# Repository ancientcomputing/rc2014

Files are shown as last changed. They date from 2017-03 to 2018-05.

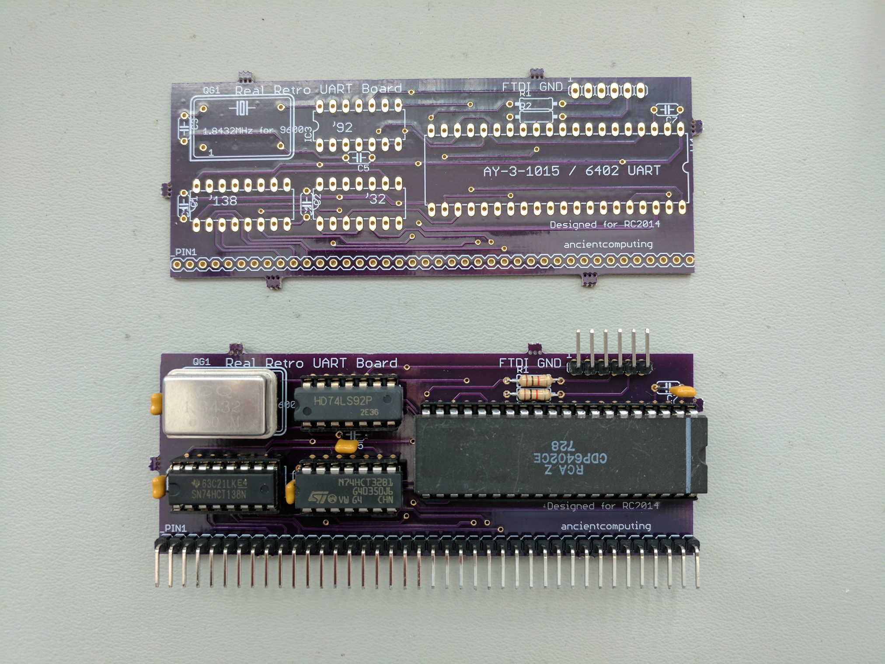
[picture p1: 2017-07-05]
eagle/realretro_uart_board/rruart-small.jpg

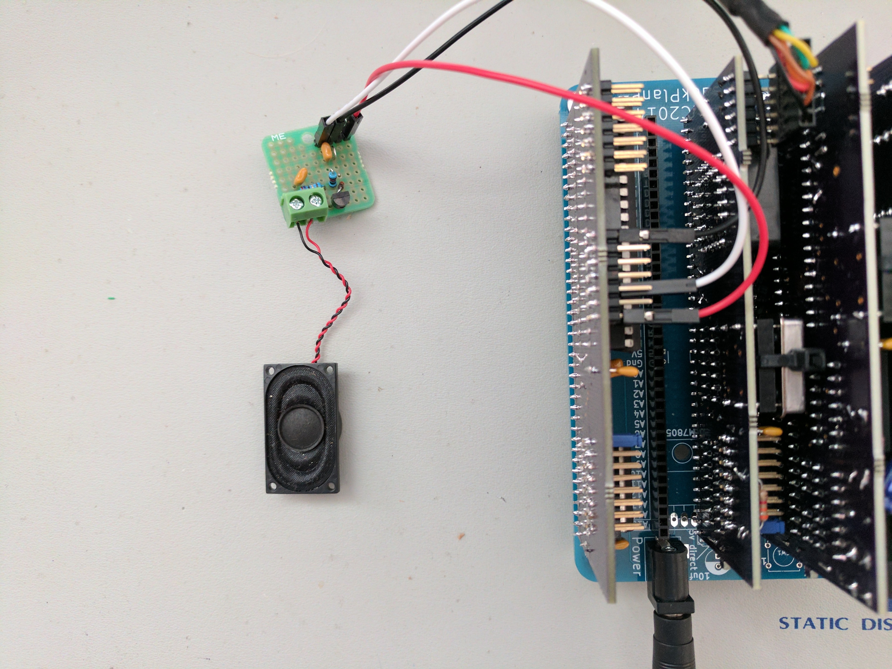
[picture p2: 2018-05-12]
source/6502/6522/speaker_board.jpg

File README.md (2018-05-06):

# RC2014
I consider Spencer Owen's RC2014 (http://rc2014.co.uk) the new S100 of the ancient computing era.
<p>
Spencer started off by designing a CPU and a family of modules around the ancient Zilog Z80 CPU. This is actually very similar to the original S100 bus design that was a derivative of the 8080 bus.
<p>
Since I'm a modder at heart, I've gone ahead and modified some of the Z80 software that originally came with the RC2014.
<p>
I have also developed a number of RC2014-compatible plug-in boards. These include a variety of memory and serial (UART) boards and more importantly, boards that allow the use of other CPUs like the <a href="https://en.wikipedia.org/wiki/Intel_8085">Intel 8085</a> and <a href="https://en.wikipedia.org/wiki/MOS_Technology_6502">6502</a> with the RC2014.
<p>
This repo holds my mods/additions and general contributions to the RC2014 community.
<p>
<hr>
<p>
<b>Software</b>
<p>
The source folder contains source code of projects related to the RC2014.
<p>
The 6502 sub-folder contains all the 6502-related source code including the Monitor/Debugger and Enhanced BASIC.
<p>
The Z80_8080 sub-folder contains all source code for Z80 and 8080 software including the Monitor/Debugger, MS BASIC, IMSAI 8K BASIC (for 8080) and various BIOS.
<p>
The original code that shipped with the RC2014 is at <a href="searle.hostei.com/grant">searle.hostei.com/grant</a>
<p>
The primary RC2014 Github repo is at: https://github.com/RC2014Z80/RC2014
<p>
<hr>
<p>
<b>ROM</b>
<p>
ROM images you can burn into EPROM/EEPROM for use with the RC2014 can be found in the ROM folder.
<p>
Not all combinations of CPU, serial, Monitor/Debugger, BASIC and ROM image sizes are available. When in doubt you can ask questions on the <a href="https://groups.google.com/forum/#!forum/rc2014-z80">RC2014 group</a> or <a href="http://forum.6502.org/">http://forum.6502.org/</a>.
<p>
<hr>
<p>
<b>RC2014 Add-on Modules</b>
<p>
The <b>eagle</b> folder contain a number of designs for add-on boards for the RC2014. The designs are in the form of Eagle files which can be used to order PCBs from manufacturers that can take .brd files. Or you can download the free version of Eagle and generate the necessary gerber files for your PCB vendor of choice.
<p>
Do also watch out for the OSH Park logos. Those are links to projects that I have shared on OSH Park, and you can order the boards directly from them. And no, I don't make a commission etc from your OSH Park orders.
<p>
For a full list of my shared projects, check out this <a href="https://oshpark.com/profiles/ancientcomputing">link</a>.
<p>
I have put some popular boards up for sale on <a href="https://www.tindie.com/stores/ancientcomputing/">Tindie</a>.
<p>
<hr>
<p>
Lastly, check out the documentation in the docs folder.
<p>
<hr>
<p>
Blog: http://ancientcomputing.blogspot.com

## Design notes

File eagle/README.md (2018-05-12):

<b>Eagle files for RC2014 add-on boards</b>
<p>
<b>16550 board (TESTED)</b>: Simple board for 16550, 16C550 and similar UART devices. Can be used with 1.8432MHz or 7.3728MHz oscillators. Note that pin 1 (GND) of the FTDI connector is on the left (looking at the board with the bus connector at the bottom).
<p>
The port address starts at 80H. A new BIOS is available. See source/16x550. Binaries are at rom/16x550.
<p>
There is no option to power the system from the FTDI header.
<p>
<b>16550 board Rev B (TESTED)</b>: A variant of the 16550 board implementation. Using 74HCT03 open collector gates, particularly to drive the /INT line. This means that other peripherals can also drive the /INT line. 
<p>
The port address starts at C0H. A new BIOS will be made available for this. For the impatient, just change the uart_base value to 0c0h from 80h.
<p>
<b>16550 board Rev C (TESTED)</b>: Yet another variant of the 16550 board implementation. This time, it uses the PLCC version of the 16550 which is still a current part. This board is also compatible with the new 16C750 which has 64-character FIFOs!
<p>
<b>z80_board (TESTED)</b>: This is an opinionated implementation of a CPU module for the RC2014. It is designed for the v1.0 bus but may work for the Pro/v2 bus. The opinionated parts of the design is a bona fide reset circuit (the firmware should start up on power up), and the use of a crystal oscillator.
<p>
The crystal oscillator can be connected to the RC2014 bus or not. The decoupling of the Z80's clock from the bus clock means that you are no longer bounded by the requirements of the UART baudrate. You will be able to run the Z80 at 20MHz (assuming you have the 20MHz part and that the bus doesn't impact the high frequency signals too much).
<p>
This Z80 board is compatible with other RC2014 modules. If you plan to use this with the 68B50 ACIA module, you will have to use a 7.3728MHz oscillator and short the CLOCK jumper.
<p>
<b>8085_board (TESTED)</b>: Use another CPU with the RC2014! The 8085 is the step-sibling of the Z80. This implementation exposes the SID/SOD lines to an FTDI header so that you can run with a serial terminal without the use of a UART card. A 6.144MHz crystal is recommended for compatibility with the Tiny Basic found <a href="https://github.com/ancientcomputing/8080_8085/tree/master/Tiny_Basic">here</a>.
<p>
A Monitor can also be found in the <a href="https://github.com/ancientcomputing/rc2014/tree/master/rom/8080_8085/monitor/">8085 folder</a>.
<p>
<b>Real Retro 3KB RAM board aka rr3kram (TESTED)</b>: Remember when 3KB was a lot of memory? The Real Retro 3KB RAM board tries to relive that experience. It uses 3 pairs of 2114 RAM chips to deliver a massive 3KB of memory.
<p>
With 200ns devices, it will even work with the Z80 CPU+ board equiped with a blistering fast 14MHz Z80.
<p>
The original board design had disconnected A0, A1 lines which have now been fixed.   
<p>
<b>Real Retro UART board (TESTED)</b>
<p>
A basic UART board using ancient UART devices like the 6402, AY-3-1015 or similar.
<p>
<b>Simple ROM/RAM board (TESTED)</b>
<p>
A simple board providing 32KB of RAM and 32KB of ROM. Usable with EPROM or EEPROM. Switchable to allow ROM at the top of memory or at the bottom of memory. This provides for compatibility with 6502 or 680x CPU boards.
<p>
<b>6502 CPU Board (TESTED)</b>
<p>
Run the 6502 microprocessor on the RC2014!
<p>
The 6502, along with the Z80, powered much of the home computer industry in the late 1970s and 1980s.
<p>
My blog <a href="https://ancientcomputing.blogspot.com">ancientcomputing.blogspot.com</a> has a number of articles that cover how the 6502 bus was made to work on the RC2014 bus and which RC2014 boards can work (with or without minor modifications) with the 6502 CPU board.
<p>
<b>6502 CPU Board RevB (TESTED)</b>
<p>
The RevB version of the 6502 CPU board gives you the option of inverting the A14 address line as well. You can use it with the RC2014 64KB RAM card to build a system with 48KB of usable RAM.
<p>
<b>6522 VIA Board (TESTED)</b>
<p>
You can start building up a 6502-based RC2014 system using native 6502 peripherals starting with the 6522 VIA board.
<p>
<hr>
<p>
<b>IMPORTANT</b>: These designs unless described otherwise are at the prototype stage as of now. I have put in the initial board orders at OSH Park and have not tested any of the designs. If you do find errors, please flag them!
<p>
kicadis are encouraged to convert the files to kicad format with the sole requirement that the converted files are made freely available aka "open source"...
<p>
Copyright Ben Chong and freely licensed back to the community.
<p>
<hr>
<p>

<p>

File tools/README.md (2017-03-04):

I found that some device programmers expect a single source file to burn an EPROM.
So romit.sh is used to combine both init32K and bas32K binaries into a single binary file.
This is a basic shell script file that works on Mac OS X and should work in a Linux environment as well.

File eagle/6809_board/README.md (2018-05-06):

<b>6809 CPU Board for the RC2014</b>
<p>
These are the EAGLE files for the RC2014 6809 CPU Board.
<p>
The A15 line selects the inverted A15 signal from the 6809. This allows you to use the standard RC2014 memory and I/O boards by inverting the 2 halves of the memory space: ROM sits at top of memory and RAM at the bottom of memory.
<p>
The I/O space is decoded by the 74HCT688 and is mapped as a 256-byte block to the start of 0C000H. You will map the Z80 I/O addresses to the 6809 I/O space by adding 0C000H.
<p>
Compatibility:
<br>TBD
<p>
You can have boards made at OSH Park at the following link:
<p>

<p>

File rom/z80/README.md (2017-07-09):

<b>ROMs for the RC2014</b>
<p>
The ROM images are organized according to which serial board (UART) they are used with.
<p>
68B50: Original RC2014 serial I/O board
<p>
sio: Dr Baker's SIO board
<p>
16x550: My original 16x550 UART board with 80h base address
<p>
16x550_revb: RevB version of my 16x550 UART board with c0h base address. This version can also be used with the RevC UART board.
<p>
ROM images for the 8085 CPU board have been moved to rom/8080_8085

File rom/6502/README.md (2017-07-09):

<b>ROM images for RC2014 6502 CPU Board</b>
<p>
monitor_ehbasic : Monitor/Debugger and Enhanced BASIC - These images are more up-to-date
<p>
monitor : Monitor/Debugger only - These images lag the source code

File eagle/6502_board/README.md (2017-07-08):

<b>6502 CPU Board for the RC2014</b>
<p>
These are the EAGLE files for the RC2014 6502 CPU Board.
<p>
Connect JP1 if you aren't using the Western Design Center 65C02 chip. This is the VPB output on the WDC chip, but on other 65(C)02 chips this has to be connected to GND.
<p>The A15 line selects the inverted A15 signal from the 6502. This allows you to use the standard RC2014 memory and I/O boards by inverting the 2 halves of the memory space: ROM sits at top of memory and RAM at the bottom of memory.
<p>
The I/O space is decoded by the 74HCT688 and is mapped as a 256-byte block to the start of 0C000H. You will map the Z80 I/O addresses to the 6502 I/O space by adding 0C000H.
<p>
Compatibility:
<br>TBD
<p>
You can have boards made at OSH Park at the following link:
<p>

<p>
Otherwise, you can order the RevB boards on <a href="https://www.tindie.com/products/9916/">Tindie</a>.

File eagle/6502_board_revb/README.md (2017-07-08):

<b>6502 CPU Board for the RC2014 RevB</b>
<p>
This is the RevB version of the board.
<p>
New:
<br>
- Optional jumper to connect R/W to pin 39 of the bus
<br>
- A14 can be inverted. Inverting A14 will allow you to use the RC2014 64KB RAM board. Configure that board for 48KB of RAM, starting from 4000h. The inverted A14 will map the 48KB to 0-BFFFh in the 6502 address space, giving you a whopping 48KB of RAM!
<br>
- NMI can be accessed with a test pin/point
<br>
- You can use a 1/2 size oscillator.
<p>
Otherwise this board works the same as the original version.
<p>
You can have boards made at OSH Park at the following link:
<br>

<p>
Otherwise, you can order boards on <a href="https://www.tindie.com/products/9916/">Tindie</a>.

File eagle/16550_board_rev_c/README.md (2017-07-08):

<b>16550 UART Board for RC2014</b>
<p>
This is RevC of the 16550 UART Board, designed for RC2014 systems.
<p>
Unlike earlier versions, this board takes the PLCC version of the 16550. I have successfully tested it with a TL16C550CFN from Mouser (part: 595-TL16C550CFN).
<p>
Also, as you can see from the Mouser part number, PLCC versions of the 16C550 are still commercially available. The DIP/DIL-40 versions are no longer so.
<p>
The use of a 16C550 in a 6502 system is important (vs the 16550 version) because the 6502 BIOS enables autoflow control. This provides a means of throttling the byte stream from your PC when you are uploading an Intel Hex file.
<p>
The other major change is the use of a 74HCT138 to give you more addressing options. This allows you to use more than one board in a system: you just need to make sure that each board uses a different port address. Of course, the software needs to be appropriately modified to access port addresses other than C0H which is the default one.
<p>
Finally, the PLCC socket is a standard part and can be ordered from Mouser (part: 806-PX-44LCC) or Jameco.
<p>
You can have boards made at OSH Park:<br>

<p> 
Or order them on <a href="https://www.tindie.com/products/9981/">Tindie</a>.

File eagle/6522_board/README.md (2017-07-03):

<b>6522 VIA Board for the RC2014</b>
<p>
These are the Eagle files for the 6522 VIA Board for the RC2014.
<p>
The board is designed to work with the 6502 CPU Board.
<p>
If you have the initial revision (revA) of the 6502 CPU board, be sure to link a wire from the R/W signal of the 6502 to pin 39 of the RC2014 bus connector. The 6522 takes the R/W signal from that pin. RevB of the 6502 CPU board does not need that change but you want to make sure that the R/W jumper is closed.
<p>
Be sure to use a 6522 that is speed matched to the 6502 CPU.
<p>
Check out some test code <a href="https://github.com/ancientcomputing/rc2014/tree/master/source/6502/6522">here</a>.

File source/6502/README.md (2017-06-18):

<b>Source code for 6502 CPU</b>
<p>
This sub-repository contains source code for programs/tools for the RC2014 6502 CPU board.
<p>
<b>monitor</b>: Simple Monitor/Debugger for the 6502
<p>
<b>ehbasic</b>: Lee Davison's Enhanced BASIC for the 6502
<p>

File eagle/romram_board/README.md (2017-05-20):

<b>Simple ROM/RAM Board for RC2014</b>
<p>
This is a simple ROM+RAM board that fully outfit an RC2014 system with memory.
<p>
Instead of ROM and RAM on separate boards, I wanted to combine them in order to reduce the number of boards needed to put together a basic system. 
<p>
The design is also very basic. Rather than trying to boil the ocean, I elected to assume the basic 32KB-32KB ROM-RAM split that is very common today among SBC designs.
<p>
The only "fancy" features are:
<br>1. Ability to select between 27256 EPROM and 28C256 EEPROM devices.
<br>2. The ability to put RAM at the top of memory à la Z80/8080 or RAM at the bottom of memory à la 6502/680x. Conversely, ROM will be at the bottom or top of memory respectively.
<p>
Fellow modders can make use of the board as a switchable ROM/RAM board by swapping in a "PAGE" signal to the A15 input of the 74HCT139.
<p>
Boards can be ordered from OSH Park at the following link:
<p>

<p>
Parts are:
<br>27256 or 28C256
<br>Most 32KB RAM devices include those that are shipped with the RC2014 RAM cards<br>74LS139, 74HCT139 or 74ACT139
<p>

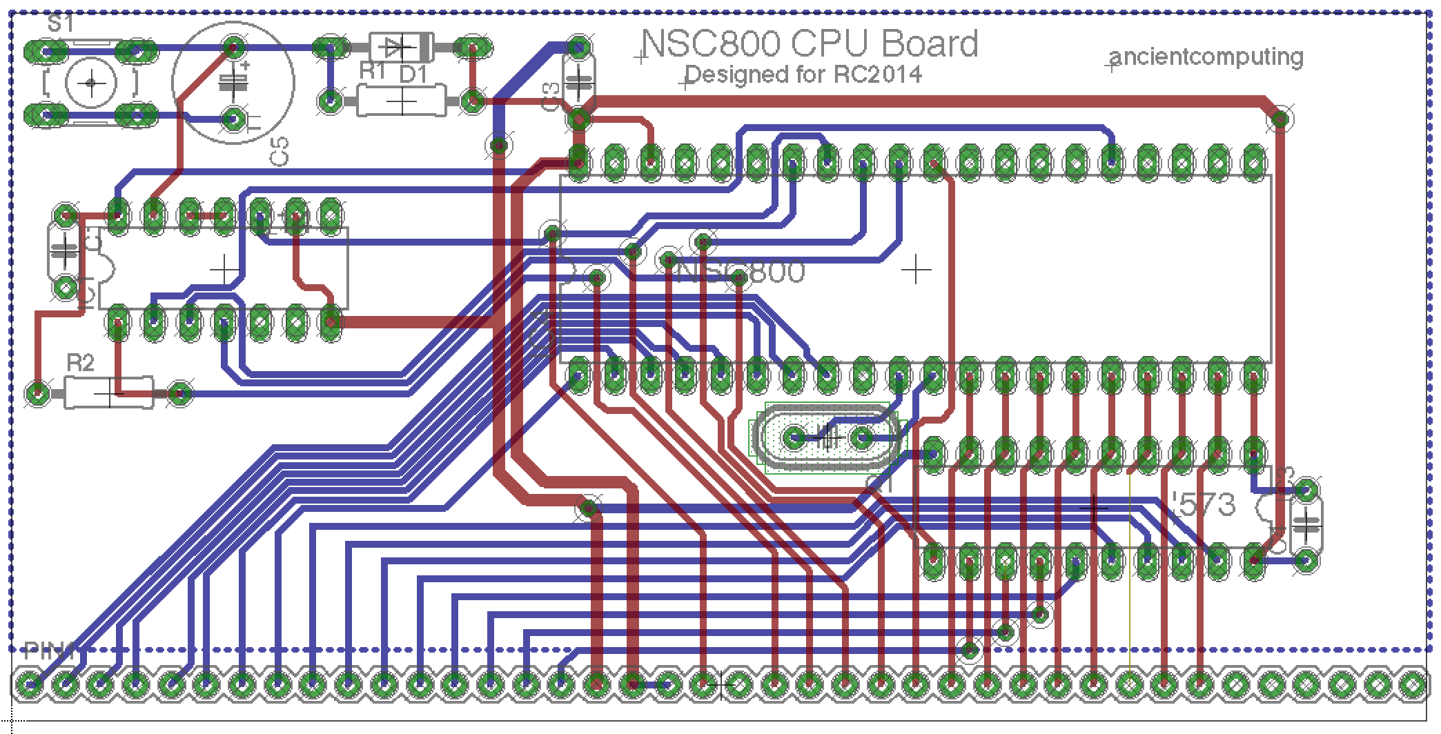
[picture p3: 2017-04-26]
eagle/NSC800_board/rc2014_nsc800.png

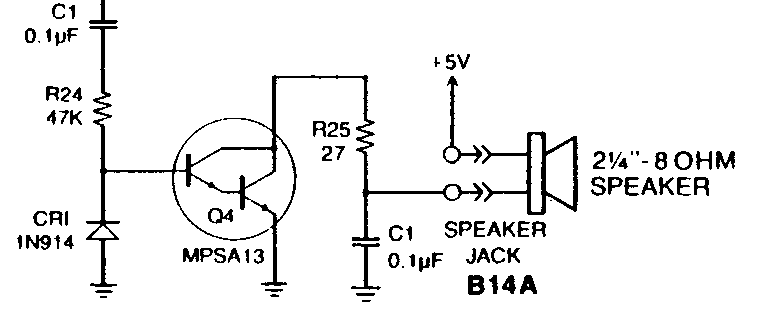
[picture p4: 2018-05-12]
source/6502/6522/a2_speaker_driver.png

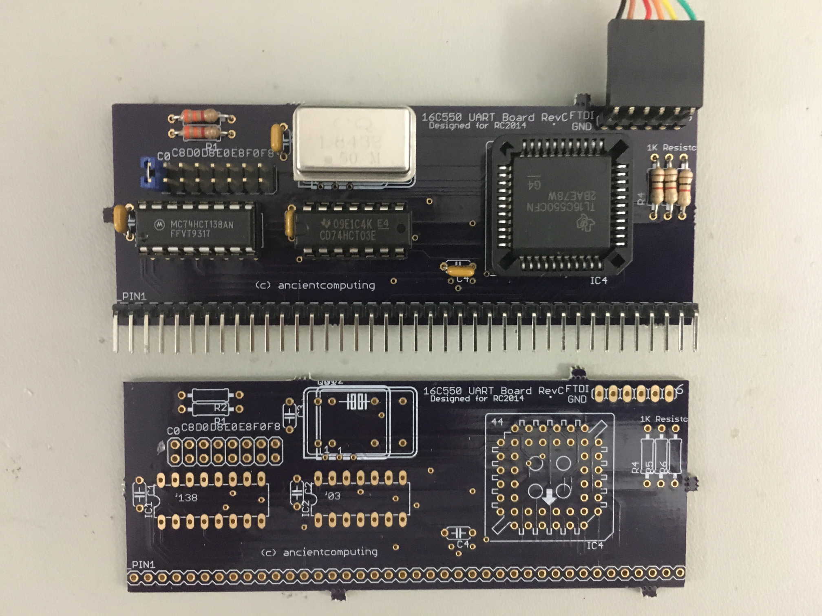
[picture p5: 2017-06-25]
eagle/16550_board_rev_c/16550_board_rev_c.jpg

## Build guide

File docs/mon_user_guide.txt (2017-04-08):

Monitor/Debugger for the RC2014
User Guide

Acknowledgements

The Monitor/Debugger for the RC2014 is based heavily on work done by others. 
Acknowledgements are in the source code.

Introduction

The Monitor/Debugger for the RC2014 is a "machine language" monitor that is very similar
in functionality to those shipped with the original microcomputers of the late 1970s to
early 1980s. This with the exception that user interaction is with a serial terminal as
opposed to a bunch of switches and LED hexadecimal displays as with the earliest 
microcomputers.

A Monitor/Debugger allows users to type in programs that they have assembled into machine
code: the actual instructions that microprocessors recognize. It also allows users to
examine and modify memory, execute programs, and set breakpoints and view registers when 
breakpoints are hit.

Many early microcomputers only came with a Monitor/Debugger. Advanced languages like BASIC
were only available as an upgrade. Later home computers dispensed with the Monitor/
Debugger and only shipped with a version of BASIC or even FORTH!

The Monitor/Debugger for the RC2014 was written for folks developing Z80 assembly code
and wanting to load, run and debug their programs on the RC2014.

Installation

The Monitor/Debugger binary is less than 4KB in size. It can be burned into a 27C512 
EPROM that is similar to the one that comes with the RC2014. You can also burn it into a
28C256 if you know how to configure the RC2014 e.g. connecting Jumper 4 on the RC2014 
Mini to Vcc.

The Monitor/Debugger binary filename is "mon.rom" and is found here:
https://github.com/ancientcomputing/rc2014/tree/master/rom

Boot

Boot the RC2014 normally e.g. connect the serial line to a computer running a terminal
emulator or an actual serial terminal, connect the power if applicable, then press and 
release the reset button.

You will see the following:
  RC2014
  Monitor >

The second line is the monitor's command line prompt.

If you press the reset button again, you will see
  RC2014
  C/W?

Press C for cold boot or W for warm boot.

Press W if you want to look at saved breakpoint registers. 

Monitor Commands

When presented with the monitor's command line prompt, you can press a key (on the 
terminal or terminal emulator) to enter a command.

Valid monitor commands are:
?              Print this help
A XXXX         Disassemble from XXXX
C              Continue from Breakpoint
D XXXX         Dump memory from XXXX
E XXXX         Edit memory from XXXX
G XXXX         Go execute from XXXX
H XXXX         Set HEX file start address to XXXX
I XX           Input from port XX
O XX YY        Output YY to port XX
R              Display registers from Breakpoint
:sHLtD...C     Load Intel HEX file, ':' is part of file

Pressing '?' will print the list of valid commands.

Running a program on the RC2014

Let's look at how you can load and execute programs on the RC2014 using the 
Monitor/Debugger.

Most Z80 assemblers or cross-assemblers will generate an Intel HEX file. This file
contains the executable Z80 machine code, but in a human readable format. Although you
will be hardpressed to understand any of it!

To run your new program on the RC2014, you will need to load the code into the RC2014 RAM.

Let's assume that you've written the following little program:

        .ORG 0C000H
        LD      HL, 0
START:
        LD      A, 0AH
        RST     08H
        LD      A, 0Dh
        RST     08H
        LD      A, 'A'
LOOP1:
        RST     08H
        INC     A
        CP      A, 'Z'+1
        JR      NZ, LOOP1
        JP      START

This little program will print the characters A to Z horizontally, then start all over 
again on a new line.

To make this program understandable by a Z80 processor, you will need to assemble it to
generate machine code.

I use the zasm cross-assembler for this. You may use other assemblers.

With zasm, you would type in the following command:
        zasm -u -x test.asm
        
Where test.asm is the text file that contains this little program.

zasm will produce a file called test.hex. If you open this file with a text editor, you 
will see the following contents:

        :170000002100003E0ACF3E0DCF015A5A3E41CF3CFE5B20FAC303C05F
        :00000001FF
        
The leading ':' symbols at the beginning of each line indicates that this is an Intel
HEX file.

The Monitor/Debugger is able to automatically understand that a ':' command means that 
the next set of data that comes over the serial console is the rest of the Intel HEX 
file.

You can either copy the file from the test editor and then paste it onto the terminal
emulator or use, if available, the built-in functions of your terminal emulator to send 
the Intel HEX file over.

For example, I use the Serial terminal emulator on a Mac. This program has a "Send Text
File" feature (Command-T). When I hit Command-T, it will ask me to choose a file to send
over to the RC2014 over the serial port.

HEX File Start Address

Before we send over the Intel HEx file, we need to understand the assembler that 
we're using and how it generates an Intel HEX file.

This is because, when you write a Z80 program, you need to specify where in the memory
space the program will reside and run. Unlike recent microprocessors, Z80 code is not
location independent without a lot of work. Immediate jump instructions, for example, 
may use absolute addresses.

In our little test program, we used the ".ORG 0C000H" command. This means that we have
assembled the code to run from memory location 0C00H (in hexadecimal values).

Unfortunately, zasm doesn't include this information in the Intel HEX file. So if you 
were to load test.hex, it will end up being written to location 0000H. This of course 
does not do anything since the Monitor/Debugger ROM resides in ROM in that location.

So before loading the test.hex file, you need to run the following command:
        h c000

Just press 'h' followed by 'c000' and ENTER.

What this does is to set the load address of the Intel HEX file data at memory location
0C000h which is where the test program need to be located in order to execute correctly.

Sending an Intel HEX file to the RC2014

Once you have set up the 'H' parameter, it is time to send the Intel HEX file to the 
RC2014.

Again, you can copy contents of the file, then paste it onto the terminal emulator
console at the Monitor > prompt.

You will get the following:

Monitor >:.
HEX TRANSFER COMPLETE ERRORS=00 0017 BYTES TRANSFERRED

The '.' is a tick mark and indicates that there was one line of actual data. The result
also indicates that there was no error and that 17H bytes (number again in hexadecimal)
was transferred.

NOTE: Some cross-assemblers set up the load address correctly. However, they do not
include the correct end-record line in the HEX file. If you see the HEX file load stop
and not do anything, press ESC to quit the load process. You will then see the "HEX
TRANSFER COMPLETE ERRORS=..." message.

Execute Your Program!

Now that you have successfully transferred the program to the RC2014, let's run it!

To run the program, type the following at the Monitor prompt:
        g c000<ENTER>

What do you see?

Since we did not include any checks in the program, the only way to halt it is to reset
the RC2014.

Once you hit reset, you will be prompted with:
        C/W?

Hit 'W' for warm start.

Exploring Memory Contents

Now, you may want to double check the contents of the test program at memory location
C000H.

To do this, hit 'D' at the command prompt, followed by the memory address and ENTER:
        d c000<ENTER>

This will give you the following output:

        C000  21 00 00 3E 0A CF 3E 0D CF 01 5A 5A 3E 41 CF 3C ; !..>..>...ZZ>A.<
        C010  FE 5B 20 FA C3 03 C0 00 00 00 10 00 00 00 01 00 ; .[ .............
        C020  FF FF 7F F6 EF 9F DF EF FE FE FF FE FF 7E FF F7 ; .............~..
        C030  00 00 00 20 10 80 00 00 00 00 00 00 00 00 00 00 ; ... ............
        C040  8A CB 45 F5 93 FE 8C DD 02 31 E4 32 EF DB F3 68 ; ..E......1.2...h
        C050  00 40 00 40 04 20 08 00 00 00 00 00 20 00 00 20 ; .@.@. ...... .. 
        C060  A2 C6 B2 DB F9 C0 7E 3C EE C0 2C 72 73 4A F8 AA ; ......~<..,rsJ..
        C070  80 44 00 00 20 80 10 00 48 00 22 04 48 00 28 40 ; .D.. ...H.".H.(@
        C080  BC FC 3F FF FB FD FF DF FF FF FF BF F7 FF FF FE ; ..?.............
        C090  00 00 00 80 00 00 00 00 00 00 00 00 00 00 00 00 ; ................
        C0A0  80 BE 97 E4 DD 52 84 6D 0F DB BD 11 FE 53 C8 E0 ; .....R.m.....S..
        C0B0  00 00 10 00 00 10 00 00 00 80 00 00 00 01 00 20 ; ............... 
        C0C0  A0 23 E7 1B 73 99 7E FD 9E DB D1 F3 B7 B5 96 2A ; .#..s.~........*
        C0D0  08 00 40 00 00 18 50 04 0A 00 20 00 00 10 C0 02 ; ..@...P... .....
        C0E0  38 E3 EB ED AB 87 F3 F3 31 7B BF DB 58 C3 3A 20 ; 8.......1{..X.: 
        C0F0  00 01 00 00 00 00 08 00 00 00 00 04 00 08 20 00 ; .............. .
        Press any key to continue, ESC to abort

As you can see the first byte of the "LD HL,0" instruction is at location C000H.

At this point, you can press any key to see memory at C100H onwards.

Alternatively, you can press ESC to go back to the Monitor prompt.

Examining and Changing Memory

What if you want to change your program without reassembling it and reloading the
Intel HEX file?

For example, in the test program, I want to start the print out with '0' instead of 'A'.

The instruction that loads the A register with 'A' is located at memory location C00CH.
This can be seen from the test.lst file that is generated when you run zasm.

At the Monitor prompt, hit E followed by c000 and ENTER:
        e c000<ENTER> 

You will see:
        C00C : 3E

Where 3E is the LD A instruction. Press 3E to enter the same value. You will see:
        C00C : 3E 3e 3E

Where the second 3e is what you typed and the third 3E is a confirmation that the value
was written to memory and successfully read back.

You will then see the content on the next memory location:
        C00D : 41

Now, 41 is the hexadecimal value for 'A'. To insert '0' instead, type 30 which is the
hexadecimal value for '0'. Thus:
        C00D : 41 30 30

Now run the program again with g c000. What do you see?

Tip: If you want to skip over an address to keep its value, you can hit RETURN

Inline Disassembler

To double check that you made the right change, the Monitor/Debugger includes an inline
disassembler.

At the Monitor prompt, press 'A' followed by c00c and ENTER. Thus:
        a c00c<ENTER>

You will see the following:

        Disassemble from C00C
        Press any key to step, ESC to abort
        C00C 3E 30       LD   A,30H

As you can see, 30H is the new value being loaded into the A register.

If you were to press any key (other than ESC), the disassembler will disassemble the next
instruction. Hence:
        C00E CF          RST  8 

This is the system call to print a character on the screen. Continue press any key to
look at the other instructions of the test program.

Then press ESC to return to the Monitor prompt.

Breakpoints

Breakpoints are places in your program where you pause the program execution. Generally
you want to use a breakpoint to understand the state of the Z80 registers and memory 
contents at a given point in your program. This is very useful for debugging and for 
learning the effect of using certain Z80 instructions that you are unfamiliar with.

To set a breakpoint, all you need to do is to insert the 'RST 30H' instruction where you
want your program to pause.

Let's insert a breakpoint just before the conditional jump instruction. The test program
will now look like:

        .ORG 0C000H
        LD      HL, 0
START:
        LD      A, 0AH
        RST     08H
        LD      A, 0Dh
        RST     08H
        LD      A, 'A'
LOOP1:
        RST     08H
        INC     A
        CP      A, 'Z'+1
        RST     30H
        JR      NZ, LOOP1
        JP      START

Now assemble the program and load the resulting Intel HEX file to the RC2014. Then use 
G command to run the program.

You will see the following:
        A
        Breakpoint at PC=C012
        AF =429B  BC =5A5A  DE =C000  HL =0000  
        AF'=4D09  BC'=FFFF  DE'=FF03  HL'=4D09  
        IX =0018  IY =0000  IR =007F  SP =81FF  
        Press C to continue or ESC to return to Monitor

The first line you see is the output of your program, when it prints the letter 'A'.

Then you see the breakpoint message, telling you that the breakpoint occurred when the 
Z80 was executing the instruction at 0C012H. This is the location where the breakpoint
instruction (RST 30H) is located.

The next 3 lines show the contents of the various Z80 registers. You can see here that
the A register now contains 42H (the B character) because we incremented it with the 
'INC A' instruction.

At this point, you can either press C to continue the program or ESC to return to the
Monitor/Debugger.

Let's try pressing C first.

Now you will see the following:
        B
        Breakpoint at PC=C012
        AF =439B  BC =5A5A  DE =C000  HL =0000  
        AF'=4D09  BC'=FFFF  DE'=FF03  HL'=4D09  
        IX =0018  IY =0000  IR =0040  SP =81FF  
        Press C to continue or ESC to return to Monitor

The first line is the program printing out the 42H value from the A register. This is
again followed by the breakpoint message, then the contents of the registers.

Now press ESC to return to the Monitor/Debugger. You will now see the Monitor prompt.

From the Monitor prompt, you can use the various commands we have already reviewed e.g. 
to look at or modify memory contents etc.

However, from the Monitor prompt, you can also press C. This command will continue the
test program from the last breakpoint!

Try it!

You will see:
        C
        Breakpoint at PC=C012
        AF =449B  BC =5A5A  DE =C000  HL =0000  
        AF'=4D09  BC'=FFFF  DE'=FF03  HL'=4D09  
        IX =0018  IY =0000  IR =0001  SP =81FF  
        Press C to continue or ESC to return to Monitor

Where the first line is the next character in the A register that is now being printed 
out.

Press ESC to return to the Monitor prompt.

From the Monitor prompt, you can press R to look at the contents of the registers.

Changing Register Contents

The Monitor/Debugger does not have a command to allow you to change breakpoint registers
directly. 

You will just need to modify the memory locations where the registers are 
stored when a breakpoint occurs. When the C command is executed, the Z80 registers are 
loaded from those memory locations.

The locations are the following:

Register        Address
A               8034H
BC              8036H
DE              8038H
HL              803AH
A'              803CH
BC'             803EH
DE'             8040H
HL'             8042H
IX              8044H
IY              8046H
SP              804AH
PC              804CH

You can use the E command to change the registers individually, then use the C command
to continue your program with the new register values.

IMPORTANT NOTE:
The breakpoint handler code in the Monitor/Debugger will switch to the Monitor stack. If
your application works with data on the stack or use subroutines, you will want to use
your own stack space.

To do this, include the following line at the start of your program:
        LD      SP, 0FFFFH

This instruction will load the Z80 Stack Pointer with 0FFFFH which will place the top
of your stack space at the top of RAM memory.

I/O Ports

The I command allows you to read from an input port.

At the Monitor prompt, press I followed by the port address:
        I 80

You will see:
        i 80 02

The value 02H is what is read from the port 80H which is the 68B50 serial port controller
of the RC2014.

The O command allows you to write a byte to an output port.

At the Monitor prompt, press O followed by the port address and data you want to output:
        I 82 41

You will see:
        o 82 41A

Now where did that 'A' come from?

Well, you just wrote 'A' to the transmit port of the 68B50 serial port controller, which
sent it to your terminal emulator program, which then displayed it!

Try writing to port 82H values like 0DH (carriage return) or 0AH (linefeed)!

!NEW! Monitor/Debugger with BASIC

A new ROM image, monbas.rom, is available at the following URL:
https://github.com/ancientcomputing/rc2014/tree/master/rom

The monbas.rom image is a 16KB image that contains both the Monitor/Debugger and a 
slightly tweaked BASIC.

To use this, you will want to use Spencer's newest Pageable ROM Module board. Set it up
for 16KB starting at address 0000H.

By default, you will always boot to the Monitor/Debugger.

To invoke BASIC, use the "G" command for address 1000H:
        g 1000

To warm start BASIC, use the 1003H address instead:
        g 1003

To switch back to the Monitor, use the "monitor" keyword in BASIC. It will basically
restart the system.

Tips and Tricks

Returning to the Monitor

To return to the Monitor/Debugger from your program, you can jump to the Monitor
warm start entry point. 

To do this insert the following line to the end of your program:
        JP      153H

153H is the memory address (in hexadecimal) of the Monitor warm start routine.

If you want to capture the contents of the CPU registers at the end of your program,
just add a breakpoint to the end i.e. thr RST 30H instruction.

Update: The new 0.7.0 version of the Monitor/Debugger/BASIC pushes the entry point of
the Monitor before calling your program. So you can use a simply RET to return to the
Monitor. Assuming that you did not change the stack, of course!

Resetting the RC2014

To reset the RC2014 from your program, just jump to memory location 0. Thus:
        JP      0H

Memory Map

The Monitor/Debugger uses RAM from 8000H to 81FFH.

Details of how this memory is used can be found in the source code.

Serial Terminal Emulator

I use a Mac for development along with an FTDI-based USB-to-serial cable. For the 
terminal emulator, I use a program called Serial. 

Serial gives you options to send files (either RAW or text) over to the RC2014.

In order to slow down the transfers so that the RC2014 does not drop characters, I set
up Serial for 1ms character delay. I also enable RTS/CTS flow control.

Update: The new 0.7.0 of the Monitor/Debugger/BASIC implements a 255-byte receive
buffer. I have found that with RTS/CTS enabled, I can reduce the character delay down
to zero.

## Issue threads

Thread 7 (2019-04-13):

8085 board possible improvements

EtchedPixels, 2019-04-13:
It would be good if the 8085 board were ever revisited if it could

- Generate M1 cycles (So you can execute ED 4D on an 8085 and trick the Z80 peripherals into thinking they saw RETI) . As ED is not documented 8085 that ought to be ok. I might just mod the board to wire the bitbang serial out to M1 though
- Allow the interrupt line to go to RST 7.5 as this is positive edge not level triggered so far more suited to RC2014 style use cases

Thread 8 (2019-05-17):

6502 revision B and non WDC parts

EtchedPixels, 2019-05-17:
Pin 1 appears to be left floating. Many 6502 parts have no internal pull-up on this pin so there should I think be a 3K3 pullup?

EtchedPixels, 2019-06-15:
Just to confirm this mod fixed my board. I guess it should be a 3 way jumper ?

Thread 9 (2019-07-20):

8085 board interrupt handling is broken

EtchedPixels, 2019-07-20:
When the 8085 gets an INT it expects an instruction to execute on the bus. As the logic on the board doens't provide one it jumps to fishkill.

The simplest mod appears to be to wire the int line to INT6.5 not INTR, as that doesn't expect such behaviour. With that simple wire patch I'm able to run with serial interrupts enabled.

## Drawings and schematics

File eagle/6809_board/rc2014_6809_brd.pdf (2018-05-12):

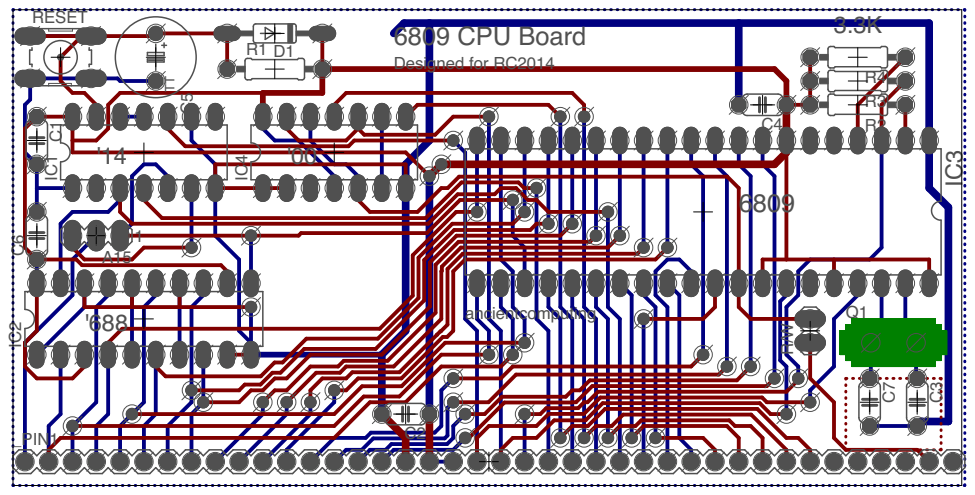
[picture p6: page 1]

TT 1 ancientcomputing '688 '14 '00 Designed for RC2014 6809 CPU Board 6809 3.3K _PIN1 C1 C2 C4 RESET C5 R1 D1 R2 IC1 R3 IC2 C6 IC4 R4 A15 IC3 Q1 C3 C7 R/W

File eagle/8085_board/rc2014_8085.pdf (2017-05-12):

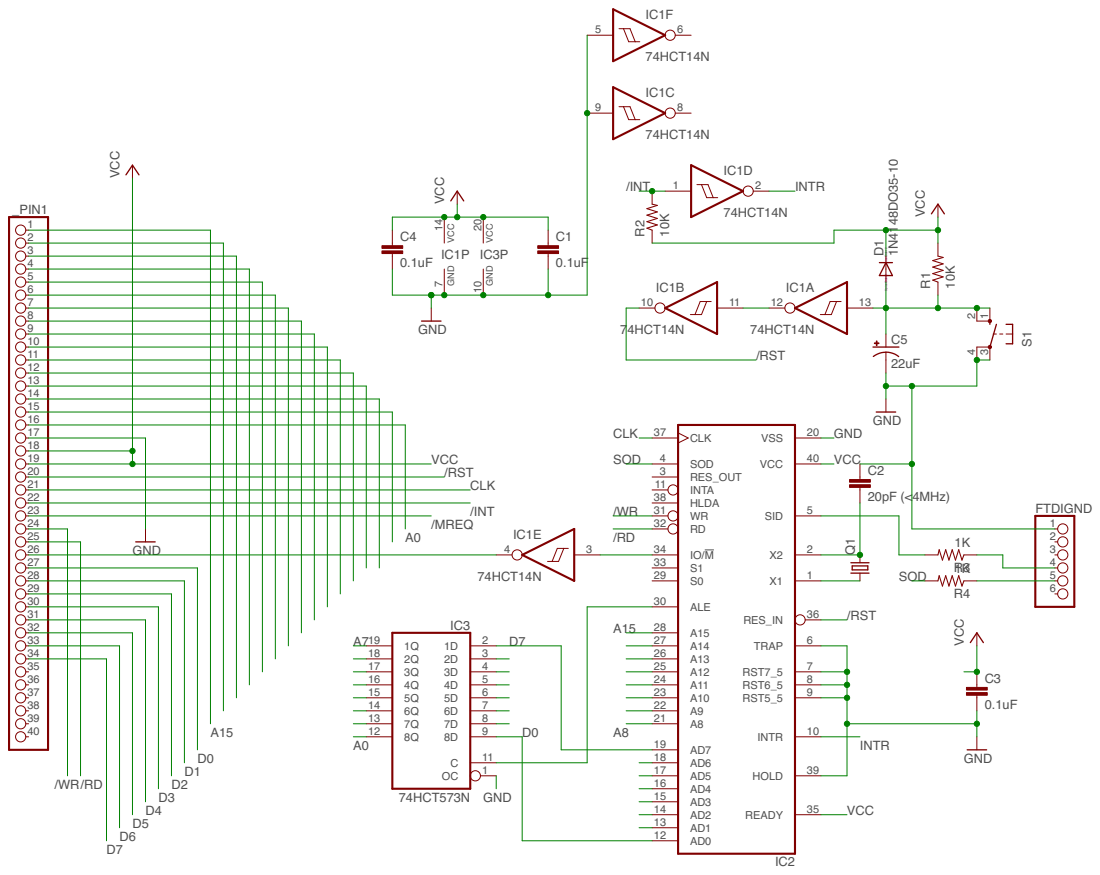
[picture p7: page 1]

SpiceOrder 1 SpiceOrder 2 0.1uF VCC VCC GND 0.1uF VCC GND 0.1uF 22uF 1N4148DO35-10 10K GND VCC 74HCT14N 74HCT14N GND 74HCT14N 74HCT14N 74HCT14N 74HCT14N 74HCT573N 20pF (<4MHz) 10K 1K1K _PIN1 12345678910111213141516171819202122232425262728293031323334353637383940 C1 C3 C4 S1 3 21 4 C5 D1 R1 IC1A 12 13 IC1B 10 11 IC1PGND VCC 7 14 IC1C 9 8 IC1D 1 2 IC1E 4 3 IC1F 5 6 IC2 AD0 12 AD1 13 AD2 14 AD3 15 AD4 16 AD5 17 AD6 18 AD7 19 A8 21 A9 22 A10 23 A11 24 A12 25 A13 26 A14 27 A15 28 ALE 30 S0 29 S1 33 IO/M 34 RD 32 WR 31 HLDA 38 INTA 11 RES_OUT 3 CLK 37 READY 35 HOLD 39 INTR 10 SOD 4 RST5_5 9 RST6_5 8 RST7_5 7 TRAP 6 RES_IN 36 X1 1 X2 2 SID 5 VCC 40 VSS 20 IC3 OC 1 1D 2 2D 3 3D 4 4D 5 5D 6 6D 7 7D 8 8D 9 C 11 8Q 12 7Q 13 6Q 14 5Q 15 4Q 16 3Q 17 2Q 18 1Q 19 Q1 IC3PGND VCC 10 20 FTDIGND 123456 C2 R2 R3 R4 A7 VCC VCCVCC D0 D0 D1 D2 D3 D4 D5 D6 D7 D7 /RST /RST /RST /INT /INT A0 A0 GND GND /WR /WR A15 A15 A8 CLK CLK /MREQ /RD /RD SOD SOD INTR INTR

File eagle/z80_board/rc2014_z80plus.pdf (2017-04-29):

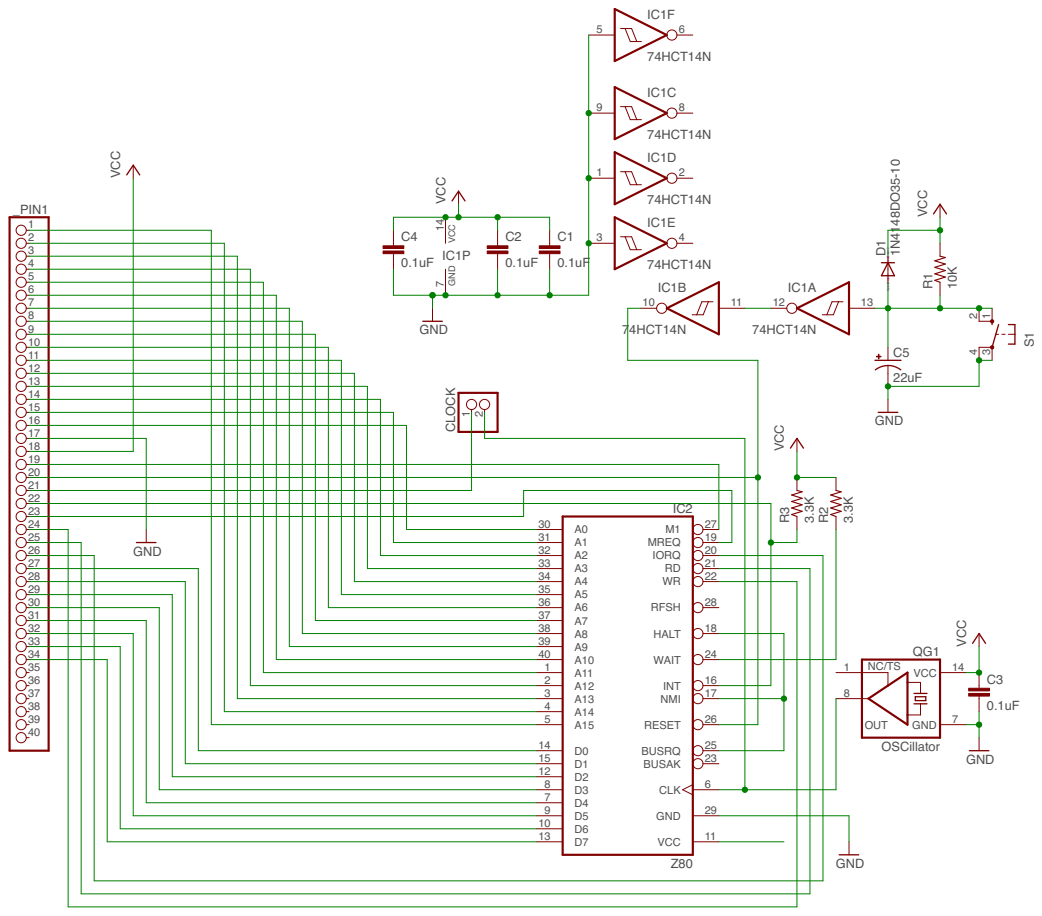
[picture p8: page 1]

SpiceOrder 1 SpiceOrder 2 0.1uF VCC VCC GND 0.1uF OSCillator 0.1uF VCC GND GND 0.1uF Z80 22uF 1N4148DO35-10 10K 3.3K GND VCC 74HCT14N 74HCT14N3.3K VCC GND 74HCT14N 74HCT14N 74HCT14N 74HCT14N _PIN1 12345678910111213141516171819202122232425262728293031323334353637383940 C2 C1 QG1 OUT GND VCC NC/TS 714 81 C3 C4 IC2 A0 30 A1 31 A2 32 A3 33 A4 34 A5 35 A6 36 A7 37 A8 38 A9 39 A10 40 A11 1 A12 2 A13 3 A14 4 A15 5 D0 14 D1 15 D2 12 D3 8 D4 7 D5 9 D6 10 D7 13 M1 27 MREQ 19 IORQ 20 RD 21 WR 22 RFSH 28 HALT 18 WAIT 24 INT 16 NMI 17 RESET 26 BUSRQ 25 BUSAK 23 CLK 6 VCC 11 GND 29 S1 3 21 C5 4 D1 R1 R2 IC1A 12 13 IC1B 10 11 R3 IC1PGND VCC 7 14 IC1C 9 8 IC1D 1 2 IC1E 3 4 IC1F 5 6 CLOCK 12

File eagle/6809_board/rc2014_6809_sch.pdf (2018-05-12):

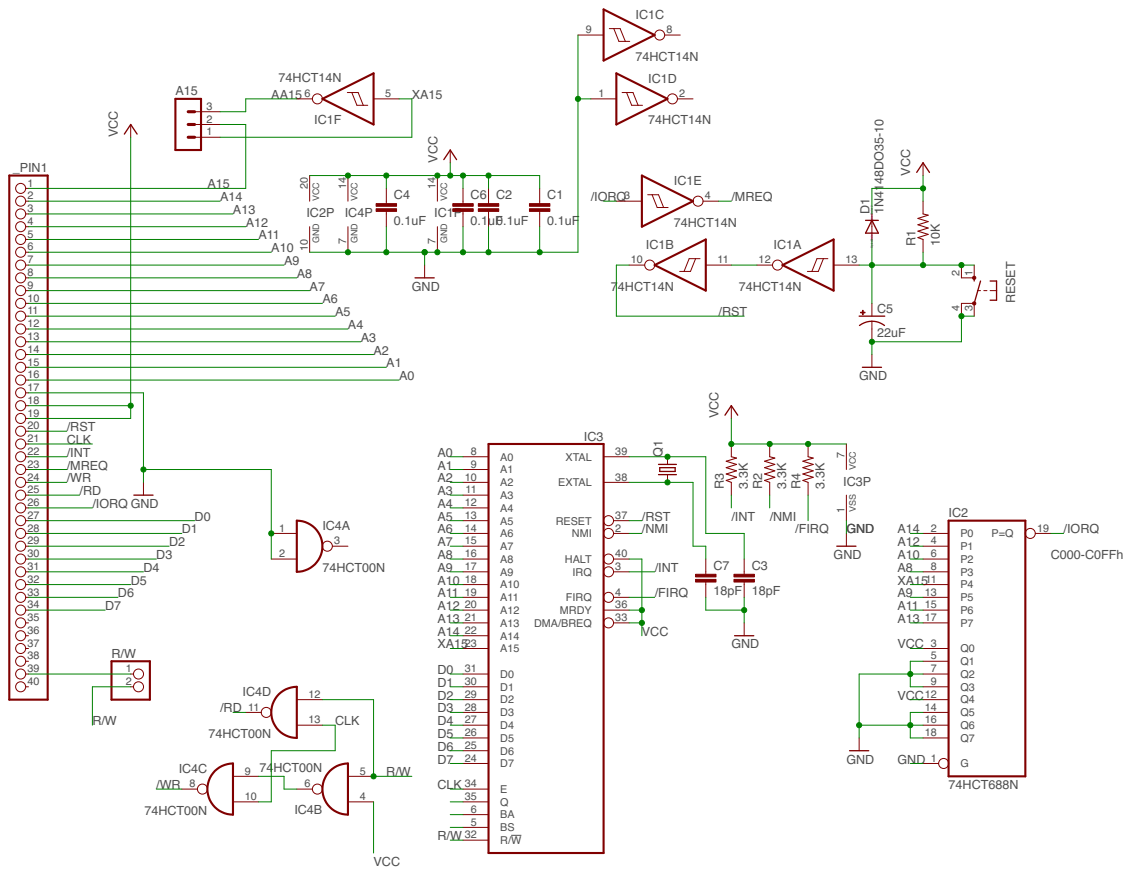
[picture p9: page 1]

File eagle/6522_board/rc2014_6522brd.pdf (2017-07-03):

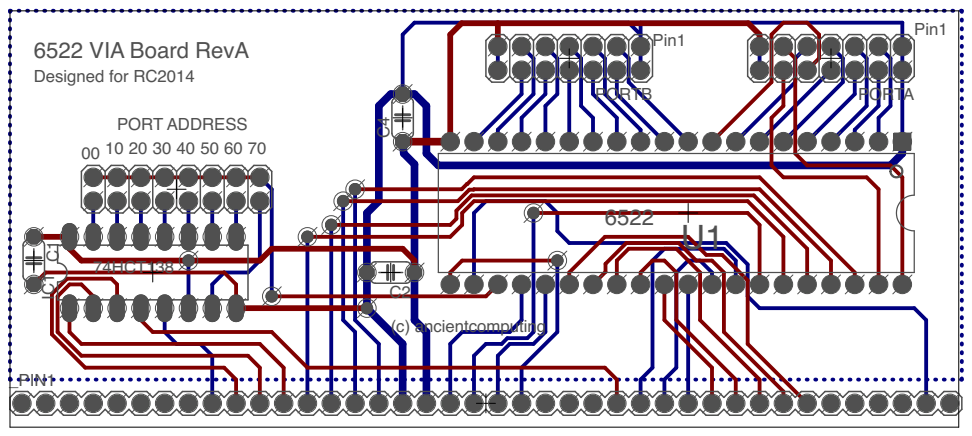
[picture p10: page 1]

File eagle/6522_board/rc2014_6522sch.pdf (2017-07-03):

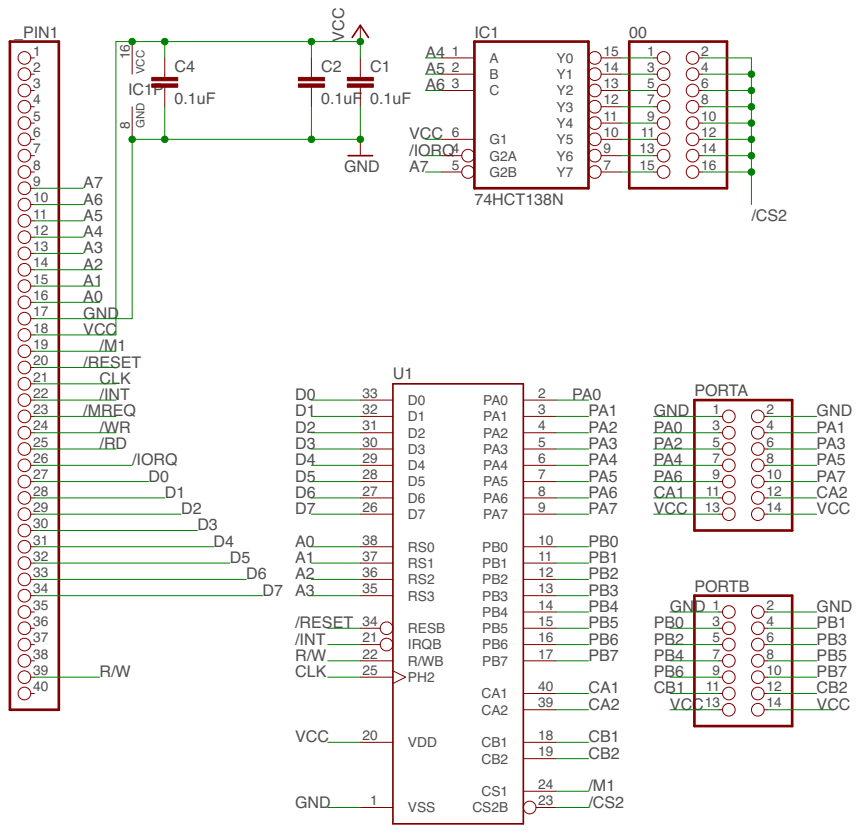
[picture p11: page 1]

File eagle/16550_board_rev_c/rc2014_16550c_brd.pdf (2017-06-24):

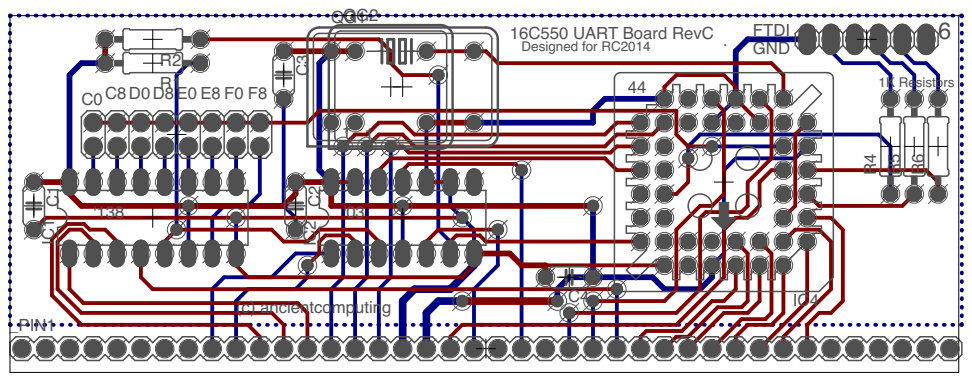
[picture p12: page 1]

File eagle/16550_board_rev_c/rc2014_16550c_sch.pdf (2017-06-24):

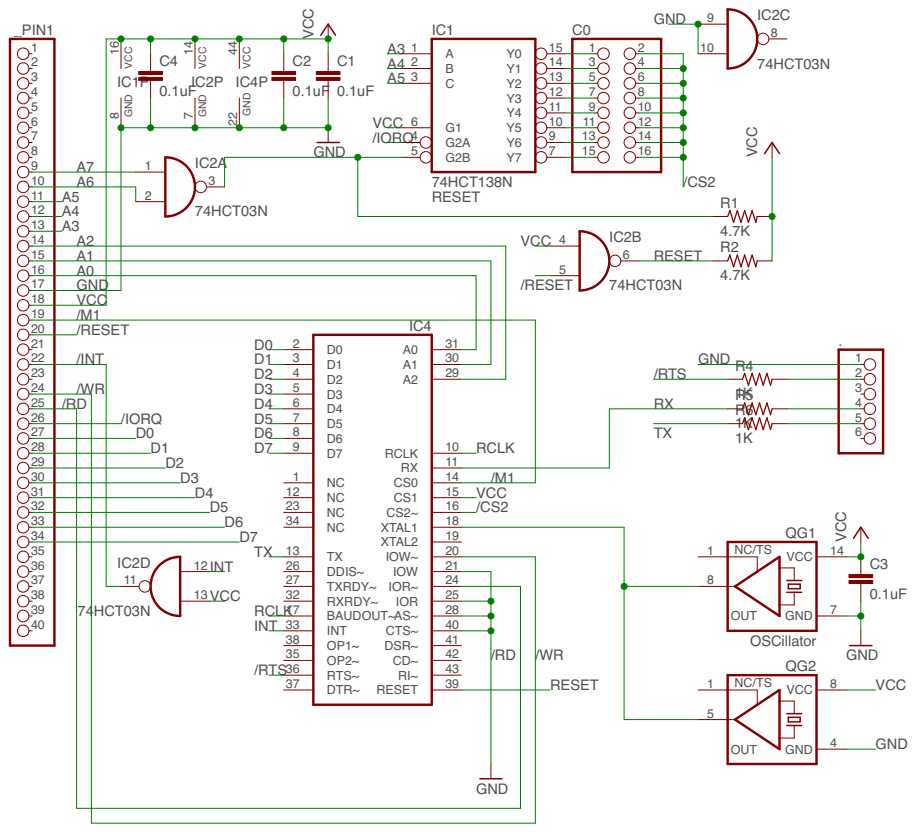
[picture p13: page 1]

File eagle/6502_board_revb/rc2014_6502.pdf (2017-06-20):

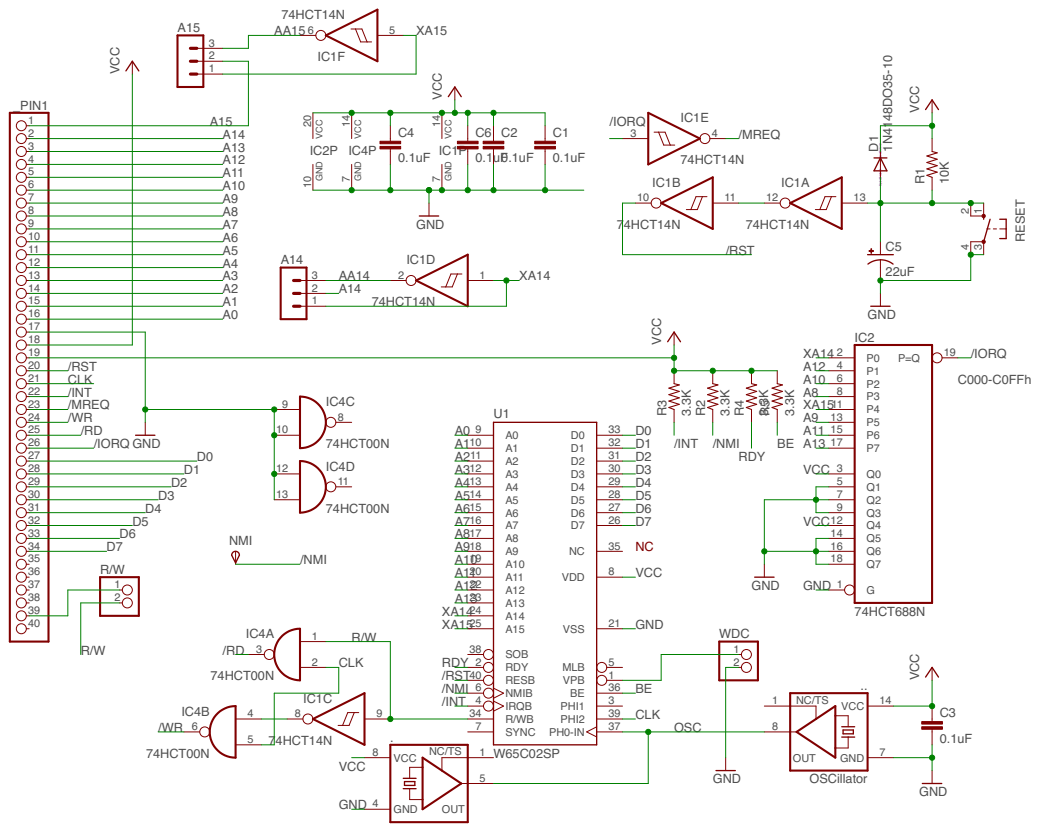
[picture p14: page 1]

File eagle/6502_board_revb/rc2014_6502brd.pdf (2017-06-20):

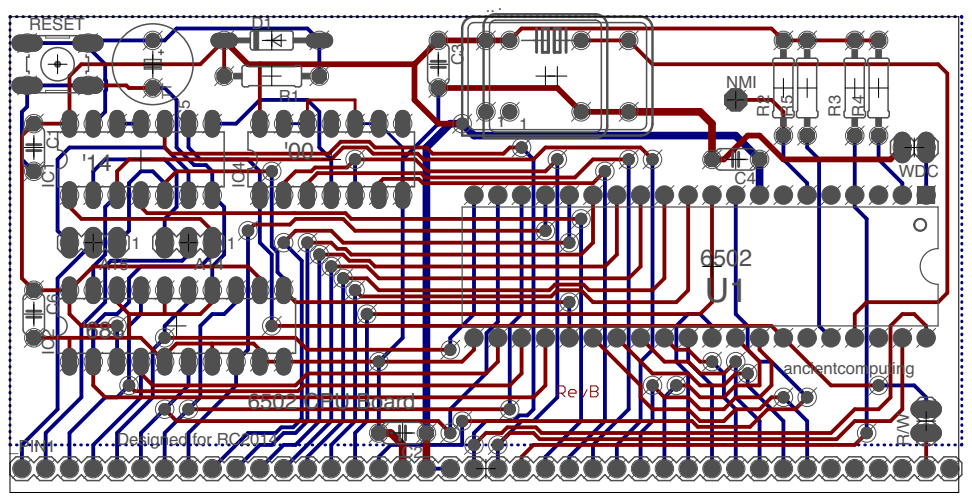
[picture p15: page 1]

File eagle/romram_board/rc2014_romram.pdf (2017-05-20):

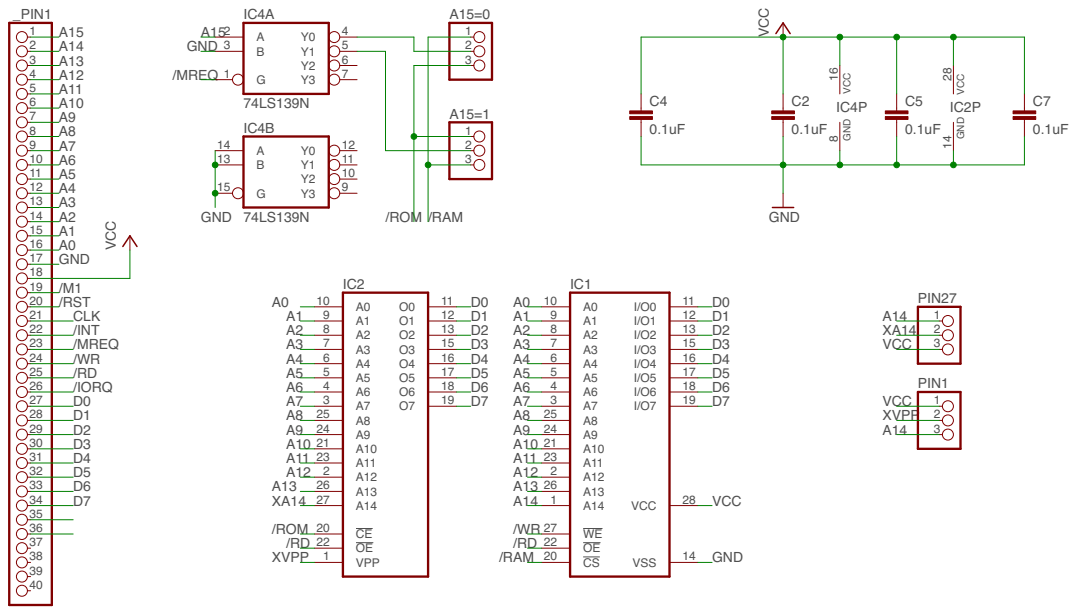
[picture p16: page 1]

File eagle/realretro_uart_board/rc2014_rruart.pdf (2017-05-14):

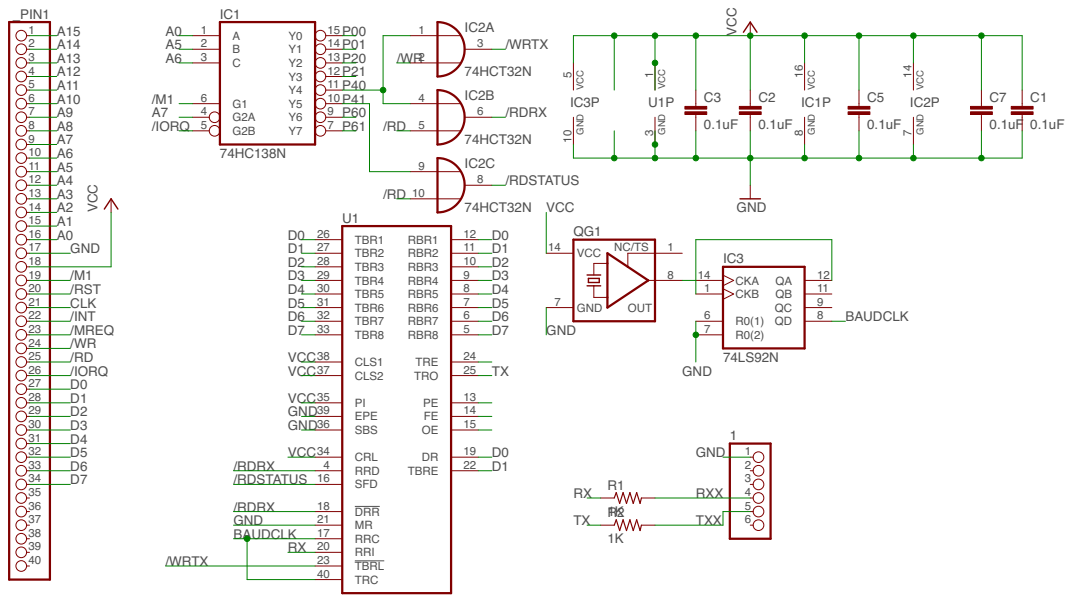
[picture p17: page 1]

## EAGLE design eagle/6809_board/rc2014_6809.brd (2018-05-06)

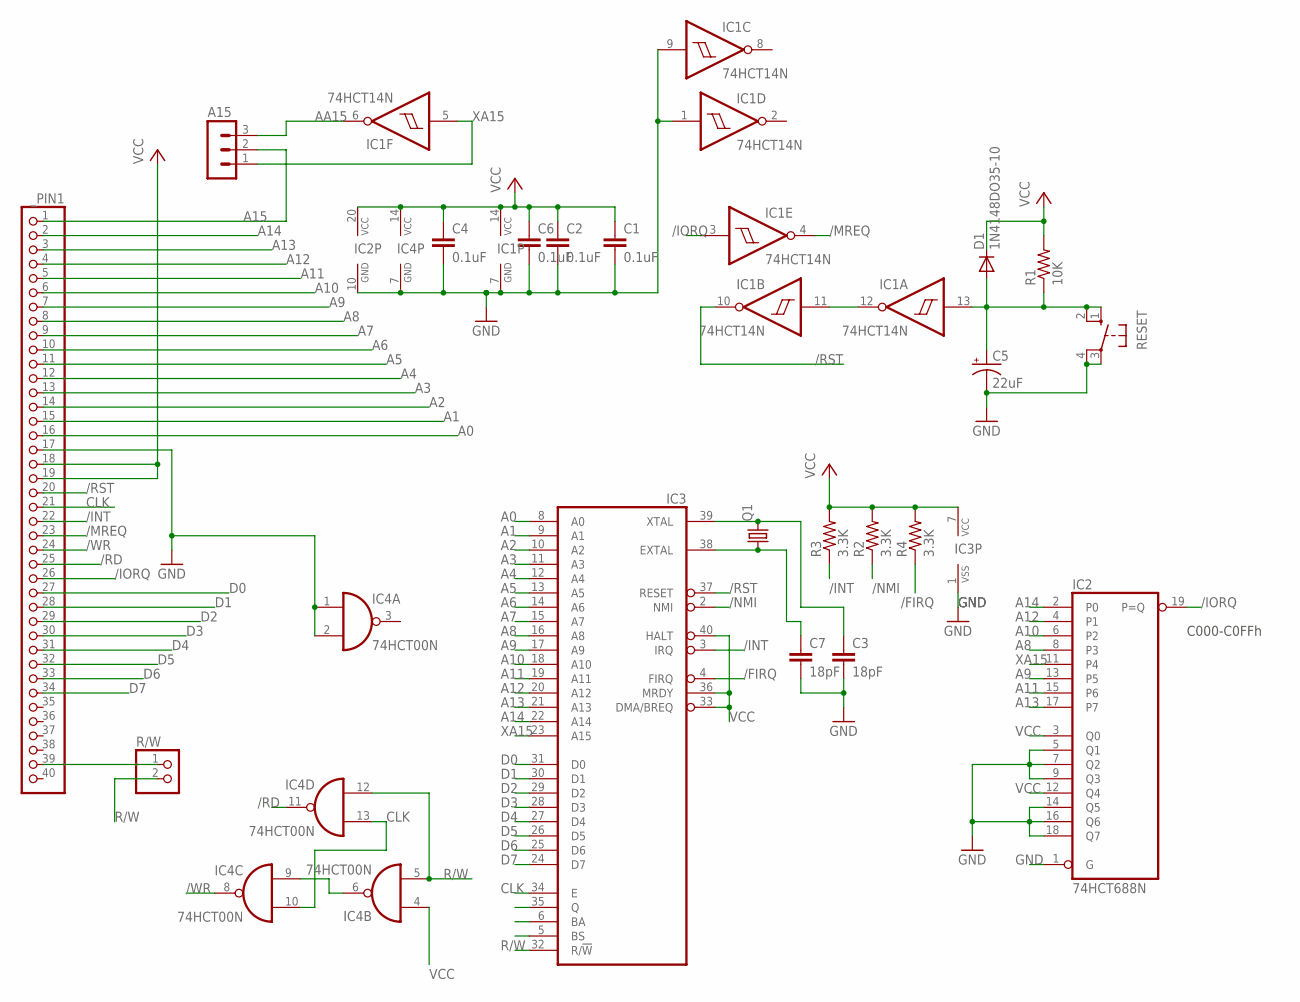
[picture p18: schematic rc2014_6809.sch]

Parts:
A15: MA03-1
C1, C2, C4, C6: 0.1uF; C050-024X044
C3, C7: 18pF; C050-024X044
C5: 22uF; TAP5-80
D1: 1N4148DO35-10; DO35-10
IC1: 74HCT14N; DIL14
IC2: 74HCT688N; DIL20
IC3: 6809; DIL40
IC4: 74HCT00N; DIL14
Q1: CRYSTALHC49S; HC49/S
R1: 10K; 0207/10
R2, R3, R4: 3.3K; 0207/10
R/W: PINHD-1X2; 1X02
RESET: 10-XX; B3F-10XX
_PIN1: PINHD-1X40; 1X40

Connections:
/FIRQ: IC3.4 (FIRQ), R4.1
/INT: IC3.3 (IRQ), R3.1, _PIN1.22
/IORQ: IC1.3 (I), IC2.19 (P=Q), _PIN1.26
/MREQ: IC1.4 (O), _PIN1.23
/NMI: IC3.2 (NMI), R2.1
/RD: IC4.11 (O), _PIN1.25
/RST: IC1.10 (O), IC3.37 (RESET), _PIN1.20
/WR: IC4.8 (O), _PIN1.24
A0: IC3.8 (A0), _PIN1.16
A1: IC3.9 (A1), _PIN1.15
A2: IC3.10 (A2), _PIN1.14
A3: IC3.11 (A3), _PIN1.13
A4: IC3.12 (A4), _PIN1.12
A5: IC3.13 (A5), _PIN1.11
A6: IC3.14 (A6), _PIN1.10
A7: IC3.15 (A7), _PIN1.9
A8: IC2.8 (P3), IC3.16 (A8), _PIN1.8
A9: IC2.13 (P5), IC3.17 (A9), _PIN1.7
A10: IC2.6 (P2), IC3.18 (A10), _PIN1.6
A11: IC2.15 (P6), IC3.19 (A11), _PIN1.5
A12: IC2.4 (P1), IC3.20 (A12), _PIN1.4
A13: IC2.17 (P7), IC3.21 (A13), _PIN1.3
A14: IC2.2 (P0), IC3.22 (A14), _PIN1.2
A15: A15.2, _PIN1.1
AA15: A15.3, IC1.6 (O)
CLK: IC3.34 (E), IC4.10 (I1), IC4.13 (I1), _PIN1.21
D0: IC3.31 (D0), _PIN1.27
D1: IC3.30 (D1), _PIN1.28
D2: IC3.29 (D2), _PIN1.29
D3: IC3.28 (D3), _PIN1.30
D4: IC3.27 (D4), _PIN1.31
D5: IC3.26 (D5), _PIN1.32
D6: IC3.25 (D6), _PIN1.33
D7: IC3.24 (D7), _PIN1.34
GND: C1.2, C2.2, C3.2, C4.2, C5.-, C6.2, C7.2, IC1.1 (I), IC1.7 (GND), IC1.9 (I), IC2.1 (G), IC2.5 (Q1), IC2.7 (Q2), IC2.9 (Q3), IC2.10 (GND), IC2.14 (Q5), IC2.16 (Q6), IC2.18 (Q7), IC3.1 (VSS), IC4.1 (I0), IC4.2 (I1), IC4.7 (GND), RESET.3, RESET.4 (P1), _PIN1.17
unnamed: IC4.6 (O), IC4.9 (I0)
unnamed: R/W.1, _PIN1.39
unnamed: IC1.11 (I), IC1.12 (O)
unnamed: C3.1, IC3.39 (XTAL), Q1.2
unnamed: C7.1, IC3.38 (EXTAL), Q1.1
R/W: IC3.32 (R/!W), IC4.5 (I1), IC4.12 (I0), R/W.2
RESET: C5.+, D1.A, IC1.13 (I), R1.1, RESET.1 (S), RESET.2 (S1)
VCC: C1.1, C2.1, C4.1, C6.1, D1.C, IC1.14 (VCC), IC2.3 (Q0), IC2.12 (Q4), IC2.20 (VCC), IC3.7 (VCC), IC3.33 (DMA/BREQ), IC3.36 (MRDY), IC3.40 (HALT), IC4.4 (I0), IC4.14 (VCC), R1.2, R2.2, R3.2, R4.2, _PIN1.18, _PIN1.19
XA15: A15.1, IC1.5 (I), IC2.11 (P4), IC3.23 (A15)

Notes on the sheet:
C000-C0FFh

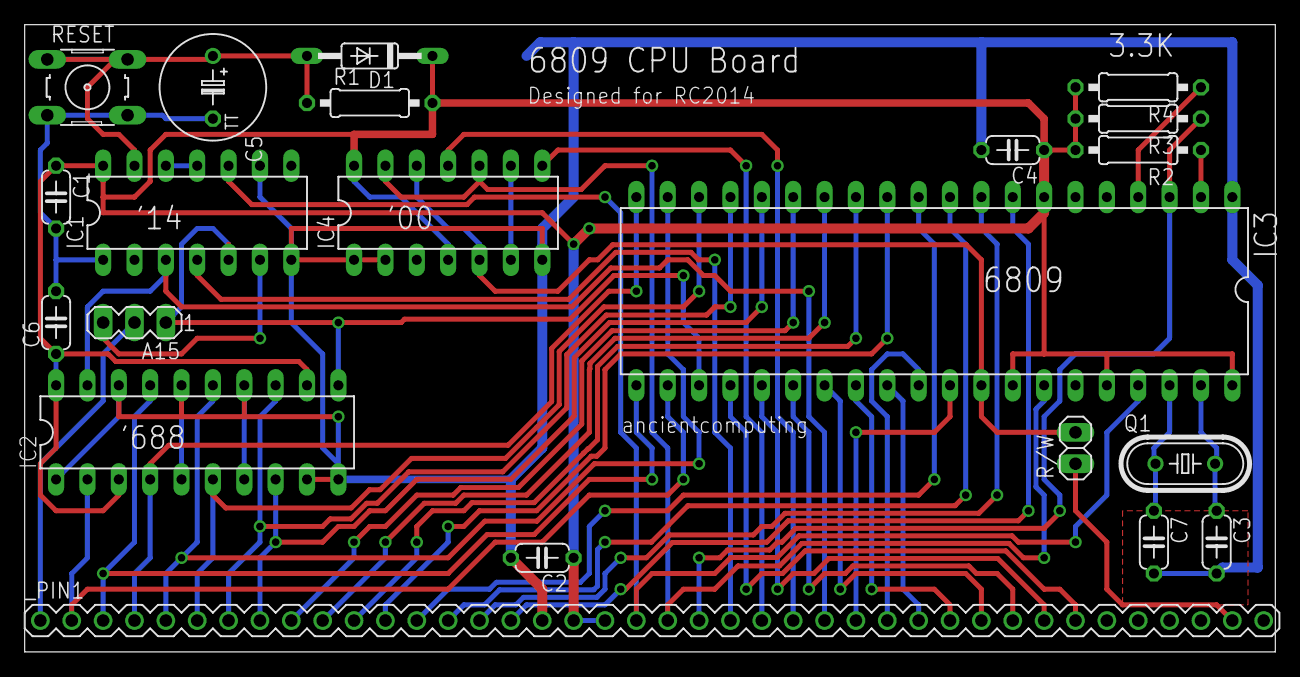
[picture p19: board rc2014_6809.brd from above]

Board: 2 copper layers, 101.3 x 50.8 mm, 21 parts (0 on the bottom side), 44 nets.

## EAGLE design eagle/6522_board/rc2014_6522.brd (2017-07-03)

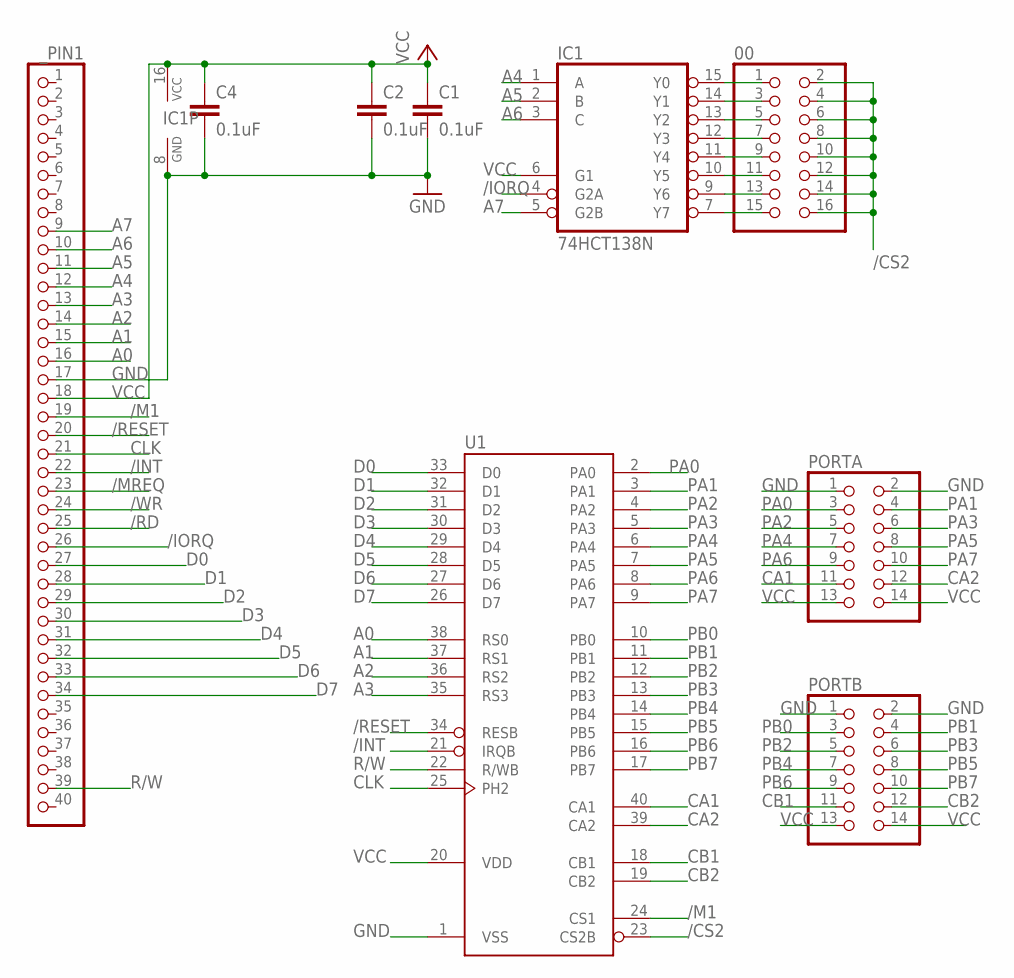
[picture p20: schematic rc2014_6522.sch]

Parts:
00: PINHD-2X8; 2X08
C1, C2, C4: 0.1uF; C050-024X044
IC1: 74HCT138N; DIL16
PORTA: PINHD-2X7; 2X07
PORTB: PINHD-2X7; 2X07
U1: G65SC22P; DIP-40
_PIN1: PINHD-1X40; 1X40

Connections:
/CS2: 00.2, 00.4, 00.6, 00.8, 00.10, 00.12, 00.14, 00.16, U1.23 (CS2B)
/INT: U1.21 (IRQB), _PIN1.22
/IORQ: IC1.4 (G2A), _PIN1.26
/M1: U1.24 (CS1), _PIN1.19
/MREQ: _PIN1.23
/RD: _PIN1.25
/RESET: U1.34 (RESB), _PIN1.20
/WR: _PIN1.24
A0: U1.38 (RS0), _PIN1.16
A1: U1.37 (RS1), _PIN1.15
A2: U1.36 (RS2), _PIN1.14
A3: U1.35 (RS3), _PIN1.13
A4: IC1.1 (A), _PIN1.12
A5: IC1.2 (B), _PIN1.11
A6: IC1.3 (C), _PIN1.10
A7: IC1.5 (G2B), _PIN1.9
CA1: PORTA.11, U1.40 (CA1)
CA2: PORTA.12, U1.39 (CA2)
CB1: PORTB.11, U1.18 (CB1)
CB2: PORTB.12, U1.19 (CB2)
CLK: U1.25 (PH2), _PIN1.21
D0: U1.33 (D0), _PIN1.27
D1: U1.32 (D1), _PIN1.28
D2: U1.31 (D2), _PIN1.29
D3: U1.30 (D3), _PIN1.30
D4: U1.29 (D4), _PIN1.31
D5: U1.28 (D5), _PIN1.32
D6: U1.27 (D6), _PIN1.33
D7: U1.26 (D7), _PIN1.34
GND: C1.2, C2.2, C4.2, IC1.8 (GND), PORTA.1, PORTA.2, PORTB.1, PORTB.2, U1.1 (VSS), _PIN1.17
unnamed: 00.1, IC1.15 (Y0)
unnamed: 00.3, IC1.14 (Y1)
unnamed: 00.5, IC1.13 (Y2)
unnamed: 00.7, IC1.12 (Y3)
unnamed: 00.9, IC1.11 (Y4)
unnamed: 00.11, IC1.10 (Y5)
unnamed: 00.13, IC1.9 (Y6)
unnamed: 00.15, IC1.7 (Y7)
PA0: PORTA.3, U1.2 (PA0)
PA1: PORTA.4, U1.3 (PA1)
PA2: PORTA.5, U1.4 (PA2)
PA3: PORTA.6, U1.5 (PA3)
PA4: PORTA.7, U1.6 (PA4)
PA5: PORTA.8, U1.7 (PA5)
PA6: PORTA.9, U1.8 (PA6)
PA7: PORTA.10, U1.9 (PA7)
PB0: PORTB.3, U1.10 (PB0)
PB1: PORTB.4, U1.11 (PB1)
PB2: PORTB.5, U1.12 (PB2)
PB3: PORTB.6, U1.13 (PB3)
PB4: PORTB.7, U1.14 (PB4)
PB5: PORTB.8, U1.15 (PB5)
PB6: PORTB.9, U1.16 (PB6)
PB7: PORTB.10, U1.17 (PB7)
R/W: U1.22 (R/WB), _PIN1.39
VCC: C1.1, C2.1, C4.1, IC1.6 (G1), IC1.16 (VCC), PORTA.13, PORTA.14, PORTB.13, PORTB.14, U1.20 (VDD), _PIN1.18

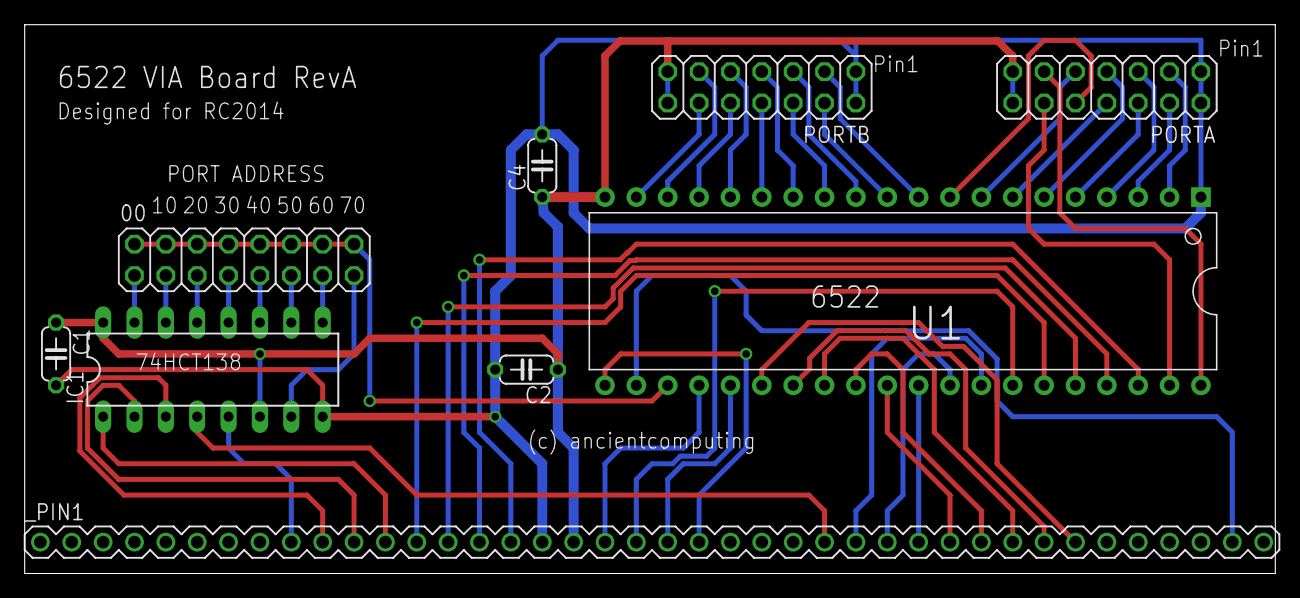
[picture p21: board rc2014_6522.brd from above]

Board: 2 copper layers, 101.3 x 44.4 mm, 9 parts (0 on the bottom side), 53 nets.

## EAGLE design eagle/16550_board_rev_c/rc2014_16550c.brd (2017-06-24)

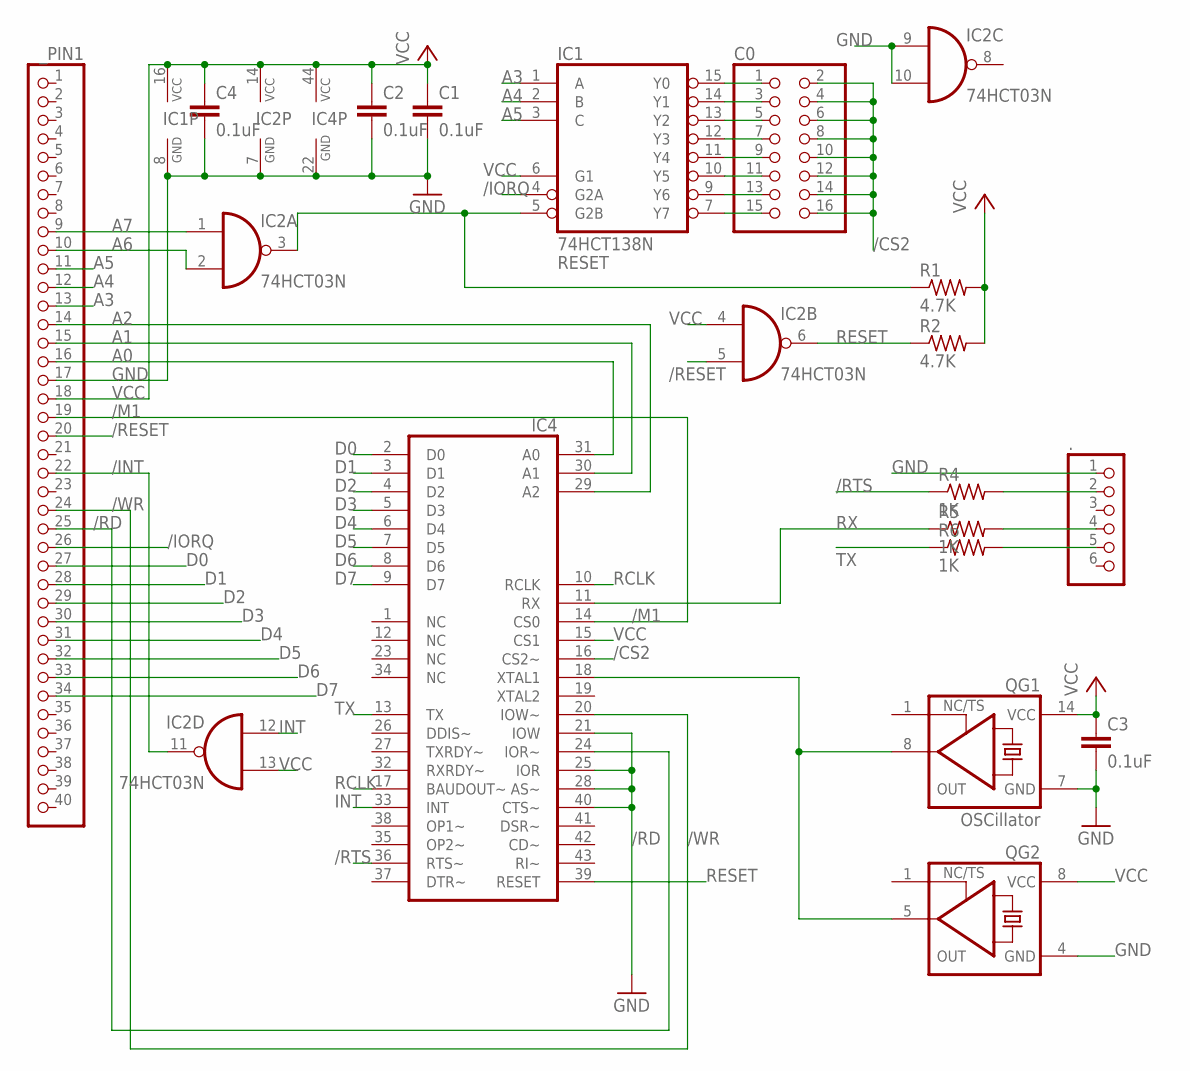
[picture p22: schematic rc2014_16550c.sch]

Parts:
.: PINHD-1X6; 1X06
C0: PINHD-2X8; 2X08
C1, C2, C3, C4: 0.1uF; C050-024X044
IC1: 74HCT138N; DIL16
IC2: 74HCT03N; DIL14
IC4: XR-16C550JSOCKET44; S44
QG1: OSCillator; DIL14S
QG2: XO-8; DIL08S
R1, R2: 4.7K; 0207/10
R4, R5, R6: 1K; 0207/10
_PIN1: PINHD-1X40; 1X40

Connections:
/CS2: C0.2, C0.4, C0.6, C0.8, C0.10, C0.12, C0.14, C0.16, IC4.16 (CS2~)
/INT: IC2.11 (O), _PIN1.22
/IORQ: IC1.4 (G2A), _PIN1.26
/M1: IC4.14 (CS0), _PIN1.19
/RD: IC4.24 (IOR~), _PIN1.25
/RESET: IC2.5 (I1), _PIN1.20
/RTS: IC4.36 (RTS~), R4.1
/WR: IC4.20 (IOW~), _PIN1.24
A0: IC4.31 (A0), _PIN1.16
A1: IC4.30 (A1), _PIN1.15
A2: IC4.29 (A2), _PIN1.14
A3: IC1.1 (A), _PIN1.13
A4: IC1.2 (B), _PIN1.12
A5: IC1.3 (C), _PIN1.11
A6: IC2.2 (I1), _PIN1.10
A7: IC2.1 (I0), _PIN1.9
CS1: IC1.5 (G2B), IC2.3 (O), R1.1
D0: IC4.2 (D0), _PIN1.27
D1: IC4.3 (D1), _PIN1.28
D2: IC4.4 (D2), _PIN1.29
D3: IC4.5 (D3), _PIN1.30
D4: IC4.6 (D4), _PIN1.31
D5: IC4.7 (D5), _PIN1.32
D6: IC4.8 (D6), _PIN1.33
D7: IC4.9 (D7), _PIN1.34
GND: ..1, C1.2, C2.2, C3.2, C4.2, IC1.8 (GND), IC2.7 (GND), IC2.9 (I0), IC2.10 (I1), IC4.21 (IOW), IC4.22 (GND), IC4.25 (IOR), IC4.28 (AS~), IC4.40 (CTS~), QG1.7 (GND), QG2.4 (GND), _PIN1.17
INT: IC2.12 (I0), IC4.33 (INT)
unnamed: ..5, R6.2
unnamed: ..4, R5.2
unnamed: ..2, R4.2
unnamed: C0.1, IC1.15 (Y0)
unnamed: C0.3, IC1.14 (Y1)
unnamed: C0.5, IC1.13 (Y2)
unnamed: C0.7, IC1.12 (Y3)
unnamed: C0.9, IC1.11 (Y4)
unnamed: C0.11, IC1.10 (Y5)
unnamed: C0.13, IC1.9 (Y6)
unnamed: C0.15, IC1.7 (Y7)
OSC: IC4.18 (XTAL1), QG1.8 (OUT), QG2.5 (OUT)
RCLK: IC4.10 (RCLK), IC4.17 (BAUDOUT~)
RESET: IC2.6 (O), IC4.39 (RESET), R2.1
RX: IC4.11 (RX), R5.1
TX: IC4.13 (TX), R6.1
VCC: C1.1, C2.1, C3.1, C4.1, IC1.6 (G1), IC1.16 (VCC), IC2.4 (I0), IC2.13 (I1), IC2.14 (VCC), IC4.15 (CS1), IC4.44 (VCC), QG1.14 (VCC), QG2.8 (VCC), R1.2, R2.2, _PIN1.18

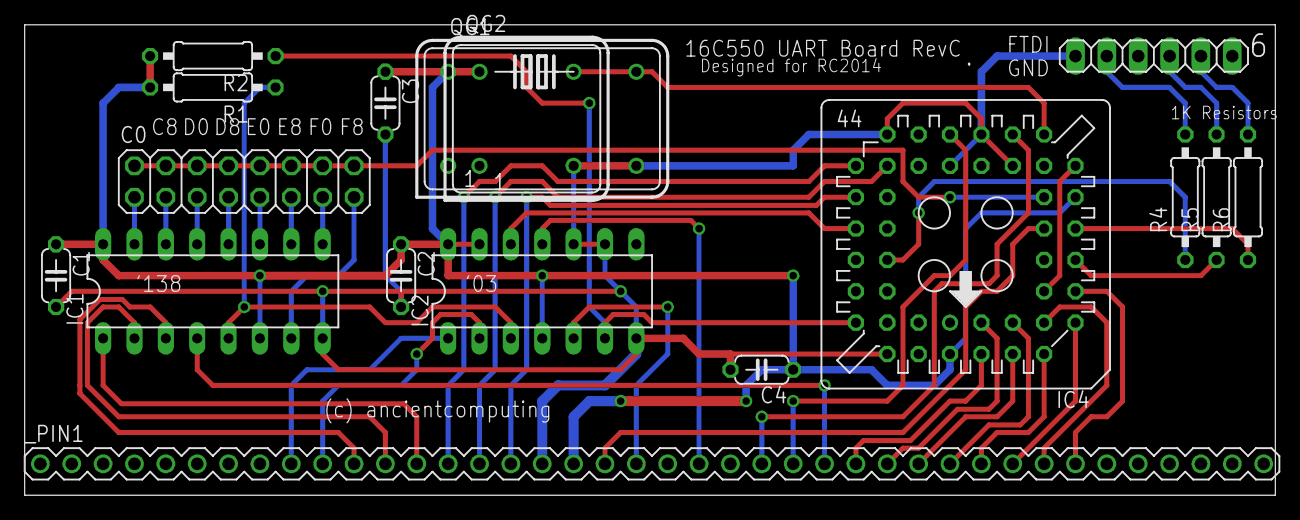
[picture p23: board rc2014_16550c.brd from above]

Board: 2 copper layers, 101.3 x 38.1 mm, 17 parts (0 on the bottom side), 44 nets.

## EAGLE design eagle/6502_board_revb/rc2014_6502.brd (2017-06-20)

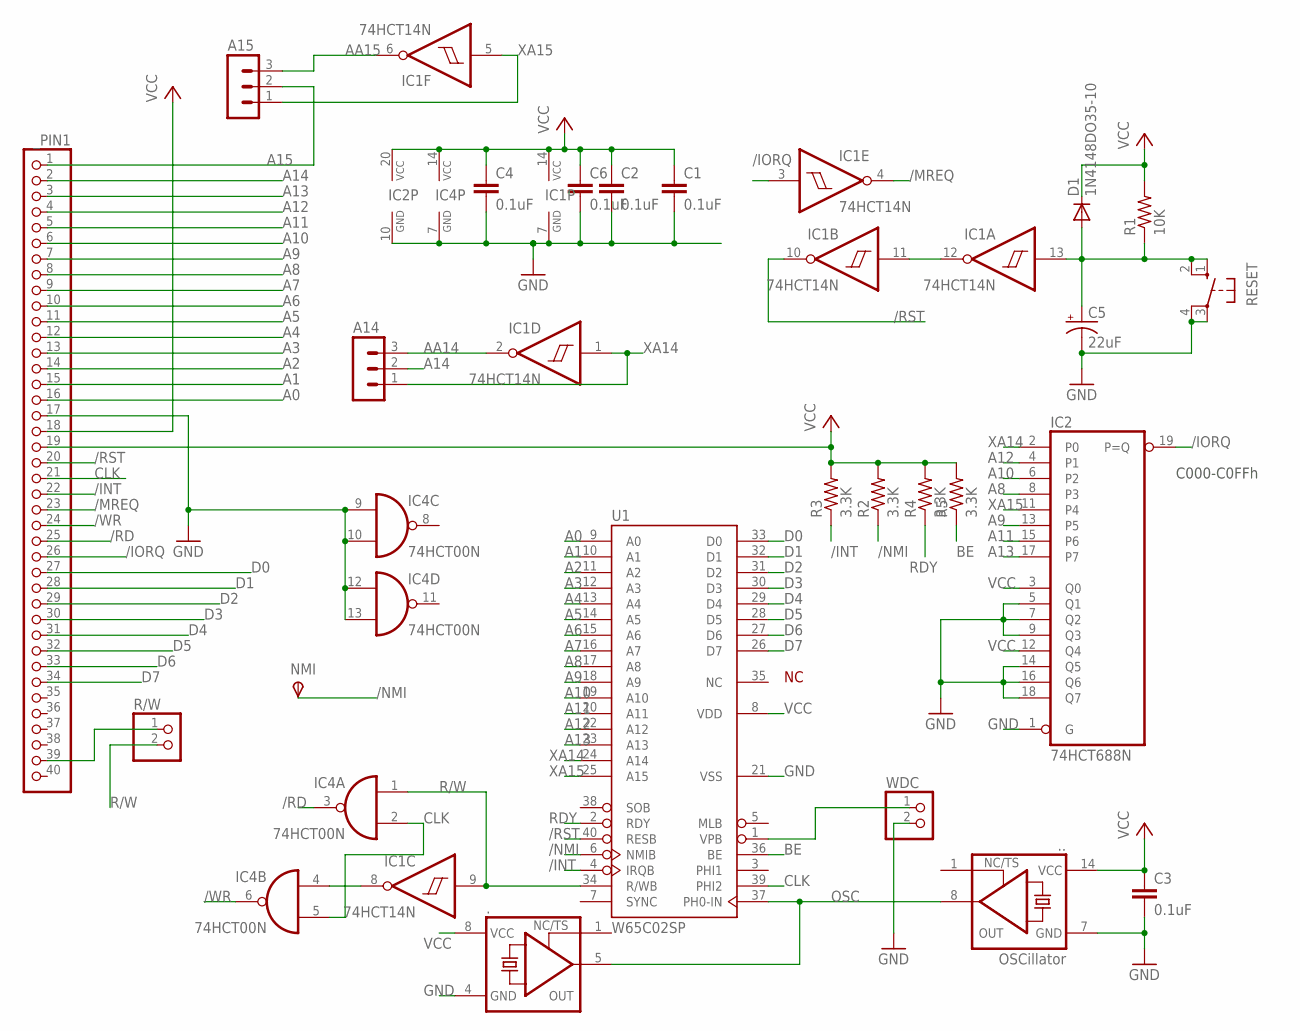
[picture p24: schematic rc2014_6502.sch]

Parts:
.: XO-8; DIL08S
..: OSCillator; DIL14S
A14, A15: MA03-1
C1, C2, C3, C4, C6: 0.1uF; C050-024X044
C5: 22uF; TAP5-80
D1: 1N4148DO35-10; DO35-10
IC1: 74HCT14N; DIL14
IC2: 74HCT688N; DIL20
IC4: 74HCT00N; DIL14
NMI: TPSPAD1-13; P1-13
R1: 10K; 0207/10
R2, R3, R4, R5: 3.3K; 0207/10
R/W: PINHD-1X2; 1X02
RESET: 10-XX; B3F-10XX
U1: W65C02SP; DIP-40
WDC: PINHD-1X2; 1X02
_PIN1: PINHD-1X40; 1X40

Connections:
/INT: R3.1, U1.4 (IRQB), _PIN1.22
/IORQ: IC1.3 (I), IC2.19 (P=Q), _PIN1.26
/MREQ: IC1.4 (O), _PIN1.23
/NMI: NMI.TP, R2.1, U1.6 (NMIB)
/RD: IC4.3 (O), _PIN1.25
/RST: IC1.10 (O), U1.40 (RESB), _PIN1.20
/WR: IC4.6 (O), _PIN1.24
A0: U1.9 (A0), _PIN1.16
A1: U1.10 (A1), _PIN1.15
A2: U1.11 (A2), _PIN1.14
A3: U1.12 (A3), _PIN1.13
A4: U1.13 (A4), _PIN1.12
A5: U1.14 (A5), _PIN1.11
A6: U1.15 (A6), _PIN1.10
A7: U1.16 (A7), _PIN1.9
A8: IC2.8 (P3), U1.17 (A8), _PIN1.8
A9: IC2.13 (P5), U1.18 (A9), _PIN1.7
A10: IC2.6 (P2), U1.19 (A10), _PIN1.6
A11: IC2.15 (P6), U1.20 (A11), _PIN1.5
A12: IC2.4 (P1), U1.22 (A12), _PIN1.4
A13: IC2.17 (P7), U1.23 (A13), _PIN1.3
A14: A14.2, _PIN1.2
A15: A15.2, _PIN1.1
AA14: A14.3, IC1.2 (O)
AA15: A15.3, IC1.6 (O)
BE: R5.1, U1.36 (BE)
CLK: IC4.2 (I1), IC4.5 (I1), U1.39 (PHI2), _PIN1.21
D0: U1.33 (D0), _PIN1.27
D1: U1.32 (D1), _PIN1.28
D2: U1.31 (D2), _PIN1.29
D3: U1.30 (D3), _PIN1.30
D4: U1.29 (D4), _PIN1.31
D5: U1.28 (D5), _PIN1.32
D6: U1.27 (D6), _PIN1.33
D7: U1.26 (D7), _PIN1.34
GND: ..4 (GND), ...7 (GND), C1.2, C2.2, C3.2, C4.2, C5.-, C6.2, IC1.7 (GND), IC2.1 (G), IC2.5 (Q1), IC2.7 (Q2), IC2.9 (Q3), IC2.10 (GND), IC2.14 (Q5), IC2.16 (Q6), IC2.18 (Q7), IC4.7 (GND), IC4.9 (I0), IC4.10 (I1), IC4.12 (I0), IC4.13 (I1), RESET.3, RESET.4 (P1), U1.21 (VSS), WDC.2, _PIN1.17
unnamed: IC1.8 (O), IC4.4 (I0)
unnamed: R/W.1, _PIN1.39
unnamed: U1.1 (VPB), WDC.1
unnamed: IC1.11 (I), IC1.12 (O)
OSC: ..5 (OUT), ...8 (OUT), U1.37 (PH0-IN)
R/W: IC1.9 (I), IC4.1 (I0), R/W.2, U1.34 (R/WB)
RDY: R4.1, U1.2 (RDY)
RESET: C5.+, D1.A, IC1.13 (I), R1.1, RESET.1 (S), RESET.2 (S1)
VCC: ..8 (VCC), ...14 (VCC), C1.1, C2.1, C3.1, C4.1, C6.1, D1.C, IC1.14 (VCC), IC2.3 (Q0), IC2.12 (Q4), IC2.20 (VCC), IC4.14 (VCC), R1.2, R2.2, R3.2, R4.2, R5.2, U1.8 (VDD), _PIN1.18, _PIN1.19
XA14: A14.1, IC1.1 (I), IC2.2 (P0), U1.24 (A14)
XA15: A15.1, IC1.5 (I), IC2.11 (P4), U1.25 (A15)

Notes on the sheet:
C000-C0FFh

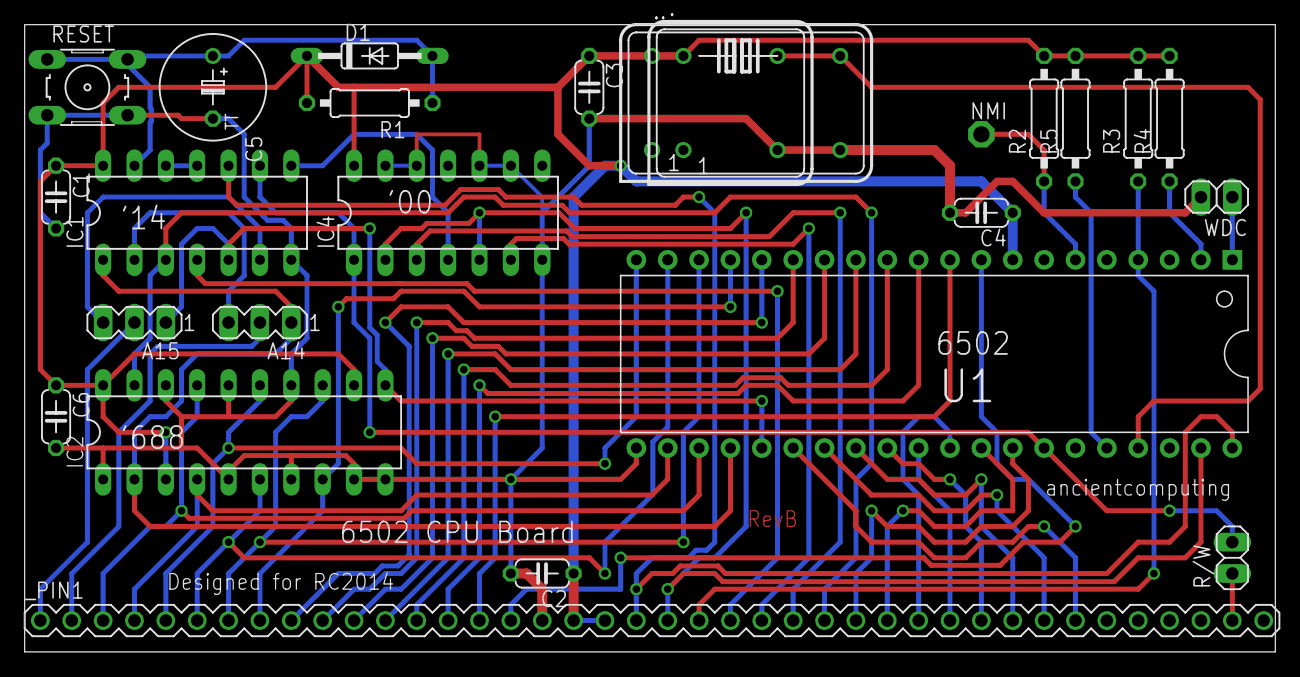
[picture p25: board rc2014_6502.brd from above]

Board: 2 copper layers, 101.3 x 50.8 mm, 25 parts (0 on the bottom side), 47 nets.

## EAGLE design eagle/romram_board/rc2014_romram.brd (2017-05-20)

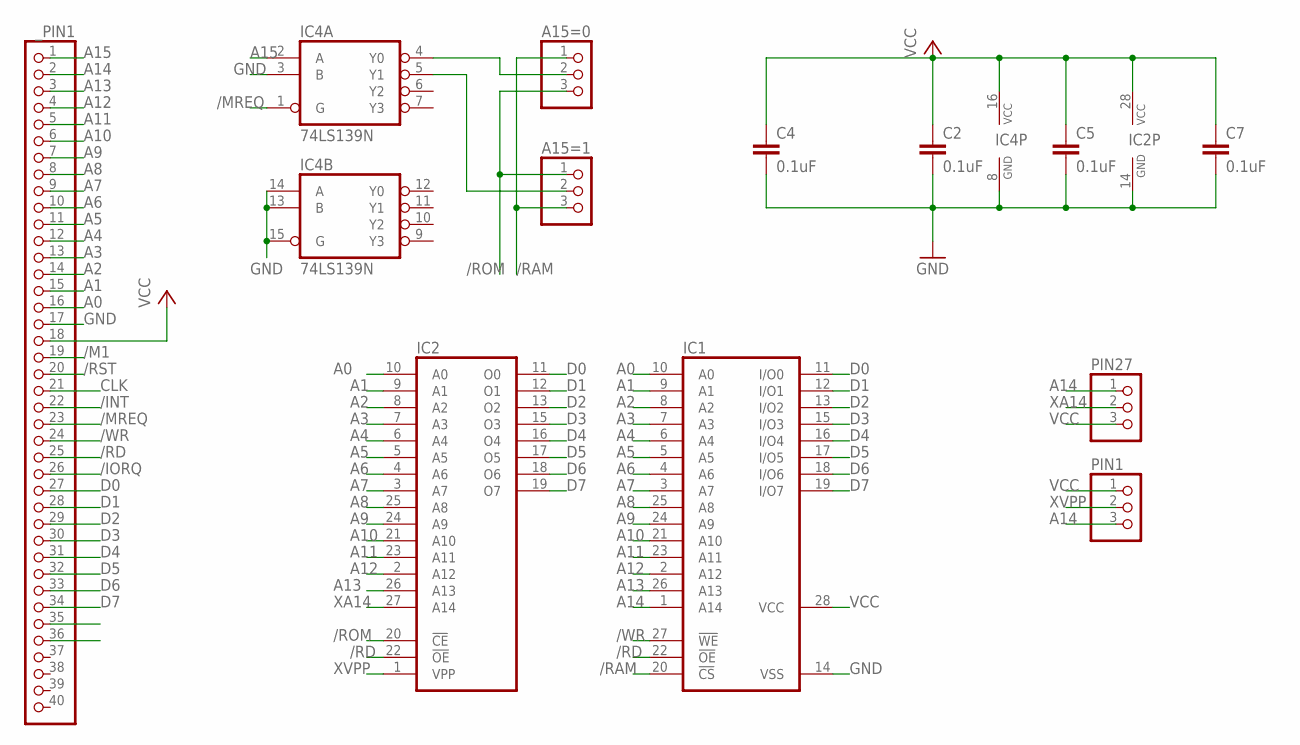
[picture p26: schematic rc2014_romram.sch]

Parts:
A15=0, A15=1: PINHD-1X3; 1X03
C2, C4, C5, C7: 0.1uF; C050-024X044
IC1: 62256P; DIL28-6
IC2: 27256; DIL28
IC4: 74LS139N; DIL16
PIN1, PIN27: PINHD-1X3; 1X03
_PIN1: PINHD-1X40; 1X40

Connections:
/INT: _PIN1.22
/IORQ: _PIN1.26
/M1: _PIN1.19
/MREQ: IC4.1 (G), _PIN1.23
/RAM: A15=0.1, A15=1.3, IC1.20 (!CS)
/RD: IC1.22 (!OE), IC2.22 (!OE), _PIN1.25
/ROM: A15=0.3, A15=1.1, IC2.20 (!CE)
/RST: _PIN1.20
/WR: IC1.27 (!WE), _PIN1.24
A0: IC1.10 (A0), IC2.10 (A0), _PIN1.16
A1: IC1.9 (A1), IC2.9 (A1), _PIN1.15
A2: IC1.8 (A2), IC2.8 (A2), _PIN1.14
A3: IC1.7 (A3), IC2.7 (A3), _PIN1.13
A4: IC1.6 (A4), IC2.6 (A4), _PIN1.12
A5: IC1.5 (A5), IC2.5 (A5), _PIN1.11
A6: IC1.4 (A6), IC2.4 (A6), _PIN1.10
A7: IC1.3 (A7), IC2.3 (A7), _PIN1.9
A8: IC1.25 (A8), IC2.25 (A8), _PIN1.8
A9: IC1.24 (A9), IC2.24 (A9), _PIN1.7
A10: IC1.21 (A10), IC2.21 (A10), _PIN1.6
A11: IC1.23 (A11), IC2.23 (A11), _PIN1.5
A12: IC1.2 (A12), IC2.2 (A12), _PIN1.4
A13: IC1.26 (A13), IC2.26 (A13), _PIN1.3
A14: IC1.1 (A14), PIN1.3, PIN27.1, _PIN1.2
A15: IC4.2 (A), _PIN1.1
CLK: _PIN1.21
D0: IC1.11 (I/O0), IC2.11 (O0), _PIN1.27
D1: IC1.12 (I/O1), IC2.12 (O1), _PIN1.28
D2: IC1.13 (I/O2), IC2.13 (O2), _PIN1.29
D3: IC1.15 (I/O3), IC2.15 (O3), _PIN1.30
D4: IC1.16 (I/O4), IC2.16 (O4), _PIN1.31
D5: IC1.17 (I/O5), IC2.17 (O5), _PIN1.32
D6: IC1.18 (I/O6), IC2.18 (O6), _PIN1.33
D7: IC1.19 (I/O7), IC2.19 (O7), _PIN1.34
GND: C2.2, C4.2, C5.2, C7.2, IC1.14 (VSS), IC2.14 (GND), IC4.3 (B), IC4.8 (GND), IC4.13 (B), IC4.14 (A), IC4.15 (G), _PIN1.17
unnamed: A15=0.2, IC4.4 (Y0)
unnamed: A15=1.2, IC4.5 (Y1)
VCC: C2.1, C4.1, C5.1, C7.1, IC1.28 (VCC), IC2.28 (VCC), IC4.16 (VCC), PIN1.1, PIN27.3, _PIN1.18
XA14: IC2.27 (A14), PIN27.2
XVPP: IC2.1 (VPP), PIN1.2

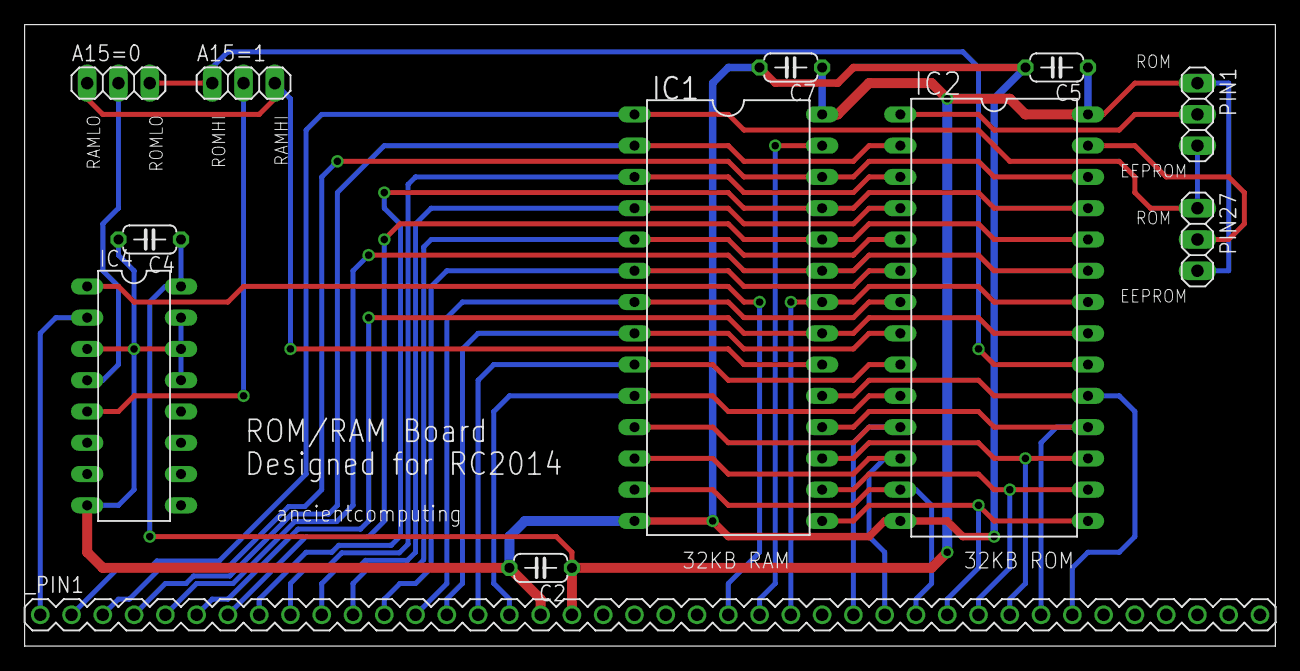
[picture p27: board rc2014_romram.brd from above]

Board: 2 copper layers, 101.6 x 50.5 mm, 12 parts (0 on the bottom side), 35 nets.

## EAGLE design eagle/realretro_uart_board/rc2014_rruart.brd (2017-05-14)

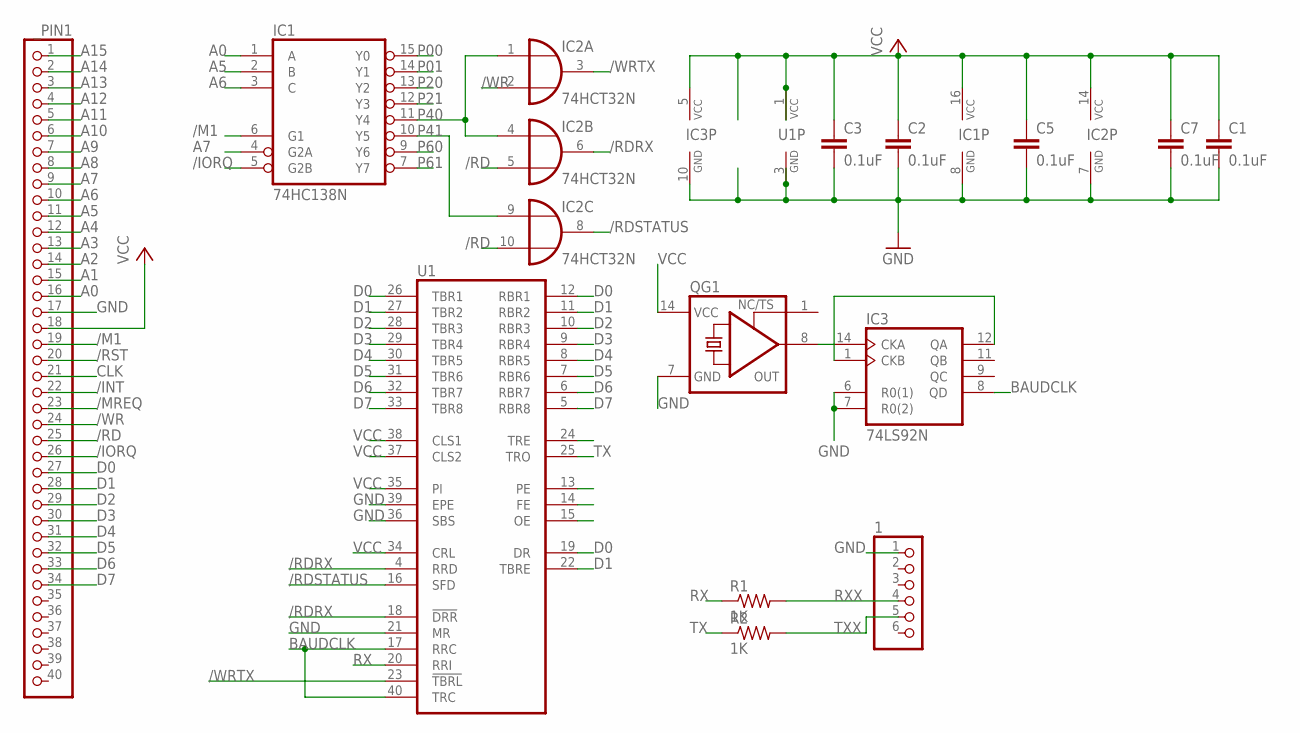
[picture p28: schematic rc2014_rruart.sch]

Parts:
1: PINHD-1X6; 1X06
C1, C2, C3, C5, C7: 0.1uF; C050-024X044
IC1: 74HC138N; DIL16
IC2: 74HCT32N; DIL14
IC3: 74LS92N; DIL14
QG1: XO-14; DIL14S
R1, R2: 1K; 0207/10
U1: HD6402; DIL40
_PIN1: PINHD-1X40; 1X40

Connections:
/INT: _PIN1.22
/IORQ: IC1.5 (G2B), _PIN1.26
/M1: IC1.6 (G1), _PIN1.19
/MREQ: _PIN1.23
/RD: IC2.5 (I1), IC2.10 (I1), _PIN1.25
/RDRX: IC2.6 (O), U1.4 (RRD), U1.18 (!DRR)
/RDSTATUS: IC2.8 (O), U1.16 (SFD)
/RST: _PIN1.20
/WR: IC2.2 (I1), _PIN1.24
/WRTX: IC2.3 (O), U1.23 (!TBRL)
A0: IC1.1 (A), _PIN1.16
A1: _PIN1.15
A2: _PIN1.14
A3: _PIN1.13
A4: _PIN1.12
A5: IC1.2 (B), _PIN1.11
A6: IC1.3 (C), _PIN1.10
A7: IC1.4 (G2A), _PIN1.9
A8: _PIN1.8
A9: _PIN1.7
A10: _PIN1.6
A11: _PIN1.5
A12: _PIN1.4
A13: _PIN1.3
A14: _PIN1.2
A15: _PIN1.1
BAUDCLK: IC3.8 (QD), U1.17 (RRC), U1.40 (TRC)
CLK: _PIN1.21
D0: U1.12 (RBR1), U1.19 (DR), U1.26 (TBR1), _PIN1.27
D1: U1.11 (RBR2), U1.22 (TBRE), U1.27 (TBR2), _PIN1.28
D2: U1.10 (RBR3), U1.28 (TBR3), _PIN1.29
D3: U1.9 (RBR4), U1.29 (TBR4), _PIN1.30
D4: U1.8 (RBR5), U1.30 (TBR5), _PIN1.31
D5: U1.7 (RBR6), U1.31 (TBR6), _PIN1.32
D6: U1.6 (RBR7), U1.32 (TBR7), _PIN1.33
D7: U1.5 (RBR8), U1.33 (TBR8), _PIN1.34
GND: 1.1, C1.2, C2.2, C3.2, C5.2, C7.2, IC1.8 (GND), IC2.7 (GND), IC3.6 (R0(1)), IC3.7 (R0(2)), IC3.10 (GND), QG1.7 (GND), U1.3 (GND), U1.21 (MR), U1.36 (SBS), U1.39 (EPE), _PIN1.17
unnamed: IC3.14 (CKA), QG1.8 (OUT)
unnamed: IC3.1 (CKB), IC3.12 (QA)
P00: IC1.15 (Y0)
P01: IC1.14 (Y1)
P20: IC1.13 (Y2)
P21: IC1.12 (Y3)
P40: IC1.11 (Y4), IC2.1 (I0), IC2.4 (I0)
P41: IC1.10 (Y5), IC2.9 (I0)
P60: IC1.9 (Y6)
P61: IC1.7 (Y7)
RX: R1.1, U1.20 (RRI)
RXX: 1.4, R1.2
TX: R2.1, U1.25 (TRO)
TXX: 1.5, R2.2
VCC: C1.1, C2.1, C3.1, C5.1, C7.1, IC1.16 (VCC), IC2.14 (VCC), IC3.5 (VCC), QG1.14 (VCC), U1.1 (VCC), U1.34 (CRL), U1.35 (PI), U1.37 (CLS2), U1.38 (CLS1), _PIN1.18

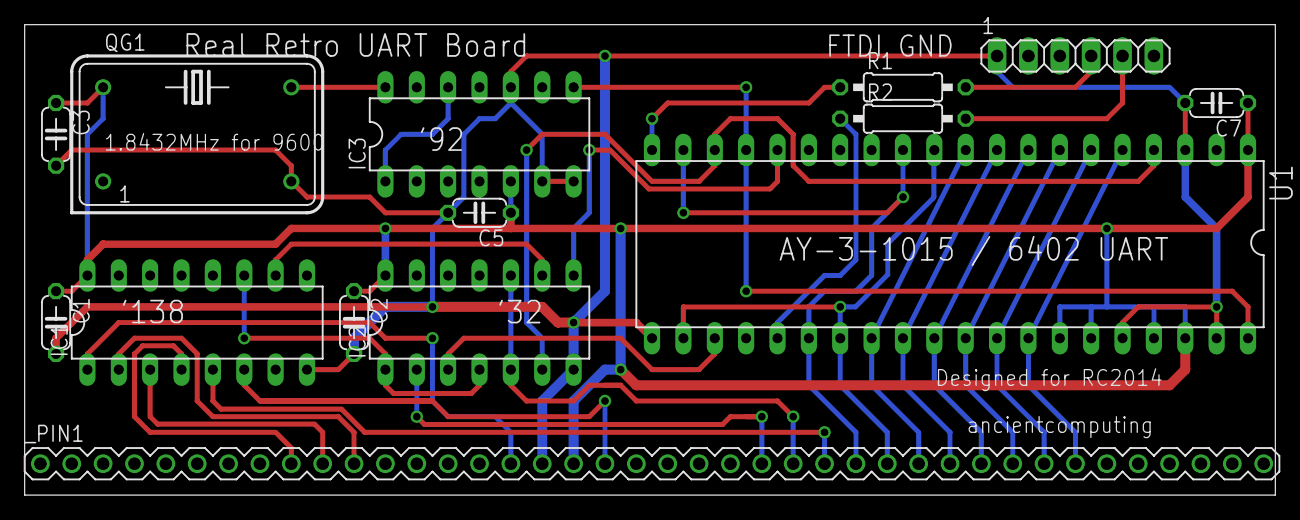
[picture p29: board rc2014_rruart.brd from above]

Board: 2 copper layers, 101.3 x 38.1 mm, 14 parts (0 on the bottom side), 30 nets.

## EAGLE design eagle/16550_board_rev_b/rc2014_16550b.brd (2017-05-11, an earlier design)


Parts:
1: PINHD-1X6; 1X06
C1, C2, C3, C4: 0.1uF; C050-024X044
IC1: 16C550; DIL40
IC2: 74HCT00N; DIL14
JP1: PINHD-1X3; 1X03
QG1: OSCillator; DIL14S
R1, R2, R3: R-US_0207/10; 0207/10
_PIN1: PINHD-1X40; 1X40

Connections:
/CS2: IC1.14 (CS2~), IC2.3 (O), R3.1
/INT: IC2.11 (O), _PIN1.22
/IORQ: IC2.10 (I1), _PIN1.26
/M1: IC1.12 (CS0), _PIN1.19
/RD: IC1.21 (IOR~), _PIN1.25
/RST: IC2.5 (I1), _PIN1.20
/RTS: 1.2, IC1.32 (RTS~)
/WR: IC1.18 (IOW~), _PIN1.24
A0: IC1.28 (A0), _PIN1.16
A1: IC1.27 (A1), _PIN1.15
A2: IC1.26 (A2), _PIN1.14
A6: IC2.2 (I1), _PIN1.10
A7: IC2.1 (I0), _PIN1.9
D0: IC1.1 (D0), _PIN1.27
D1: IC1.2 (D1), _PIN1.28
D2: IC1.3 (D2), _PIN1.29
D3: IC1.4 (D3), _PIN1.30
D4: IC1.5 (D4), _PIN1.31
D5: IC1.6 (D5), _PIN1.32
D6: IC1.7 (D6), _PIN1.33
D7: IC1.8 (D7), _PIN1.34
GND: 1.1, C1.2, C2.2, C3.2, C4.2, IC1.19 (IOW), IC1.20 (GND), IC1.22 (IOR), IC1.25 (AS~), IC1.36 (CTS~), IC2.7 (GND), JP1.2, QG1.7 (GND), _PIN1.17
INT: IC1.30 (INT), IC2.12 (I0)
IORQ: IC1.13 (CS1), IC2.8 (O), R1.1
unnamed: IC1.34 (OP1~), JP1.3
unnamed: IC1.31 (OP2~), JP1.1
unnamed: IC1.9 (RCLK), IC1.15 (BAUDOUT~)
OSC: IC1.16 (XTAL1), QG1.8 (OUT)
RESET: IC1.35 (RESET), IC2.6 (O), R2.1
RX: 1.4, IC1.10 (RX)
TX: 1.5, IC1.11 (TX)
VCC: C1.1, C2.1, C3.1, C4.1, IC1.40 (VCC), IC2.4 (I0), IC2.9 (I0), IC2.13 (I1), IC2.14 (VCC), QG1.14 (VCC), R1.2, R2.2, R3.2, _PIN1.18


Board: 2 copper layers, 101.3 x 38.1 mm, 13 parts (0 on the bottom side), 32 nets.

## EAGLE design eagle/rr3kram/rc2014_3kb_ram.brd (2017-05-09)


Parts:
C1, C2, C3, C4, C5, C6, C7: 0.1uF; C050-024X044
IC1, IC2, IC3, IC4, IC5, IC6: 2114; DIL18
IC7: 74LS138N; DIL16
JP1, JP2: PINHD-2X3; 2X03
_PIN1: PINHD-1X40; 1X40

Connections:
/INT: _PIN1.22
/IORQ: _PIN1.26
/M1: _PIN1.19
/MREQ: IC7.4 (G2A), _PIN1.23
/RAM0: IC1.8 (!CS), IC4.8 (!CS), JP1.2, JP2.2
/RAM1: IC2.8 (!CS), IC5.8 (!CS), JP1.4, JP2.4
/RAM2: IC3.8 (!CS), IC6.8 (!CS), JP1.6, JP2.6
/RD: _PIN1.25
/RST: _PIN1.20
/WR: IC1.10 (!WE), IC2.10 (!WE), IC3.10 (!WE), IC4.10 (!WE), IC5.10 (!WE), IC6.10 (!WE), _PIN1.24
A0: IC1.5 (A0), IC2.5 (A0), IC3.5 (A0), IC4.5 (A0), IC5.5 (A0), IC6.5 (A0), _PIN1.16
A1: IC1.6 (A1), IC2.6 (A1), IC3.6 (A1), IC4.6 (A1), IC5.6 (A1), IC6.6 (A1), _PIN1.15
A2: IC1.7 (A2), IC2.7 (A2), IC3.7 (A2), IC4.7 (A2), IC5.7 (A2), IC6.7 (A2), _PIN1.14
A3: IC1.4 (A3), IC2.4 (A3), IC3.4 (A3), IC4.4 (A3), IC5.4 (A3), IC6.4 (A3), _PIN1.13
A4: IC1.3 (A4), IC2.3 (A4), IC3.3 (A4), IC4.3 (A4), IC5.3 (A4), IC6.3 (A4), _PIN1.12
A5: IC1.2 (A5), IC2.2 (A5), IC3.2 (A5), IC4.2 (A5), IC5.2 (A5), IC6.2 (A5), _PIN1.11
A6: IC1.1 (A6), IC2.1 (A6), IC3.1 (A6), IC4.1 (A6), IC5.1 (A6), IC6.1 (A6), _PIN1.10
A7: IC1.17 (A7), IC2.17 (A7), IC3.17 (A7), IC4.17 (A7), IC5.17 (A7), IC6.17 (A7), _PIN1.9
A8: IC1.16 (A8), IC2.16 (A8), IC3.16 (A8), IC4.16 (A8), IC5.16 (A8), IC6.16 (A8), _PIN1.8
A9: IC1.15 (A9), IC2.15 (A9), IC3.15 (A9), IC4.15 (A9), IC5.15 (A9), IC6.15 (A9), _PIN1.7
A10: IC7.1 (A), _PIN1.6
A11: IC7.2 (B), _PIN1.5
A12: IC7.3 (C), _PIN1.4
A13: _PIN1.3
A14: IC7.5 (G2B), _PIN1.2
A15: IC7.6 (G1), _PIN1.1
CLK: _PIN1.21
D0: IC1.14 (D0), IC2.14 (D0), IC3.14 (D0), _PIN1.27
D1: IC1.13 (D1), IC2.13 (D1), IC3.13 (D1), _PIN1.28
D2: IC1.12 (D2), IC2.12 (D2), IC3.12 (D2), _PIN1.29
D3: IC1.11 (D3), IC2.11 (D3), IC3.11 (D3), _PIN1.30
D4: IC4.14 (D0), IC5.14 (D0), IC6.14 (D0), _PIN1.31
D5: IC4.13 (D1), IC5.13 (D1), IC6.13 (D1), _PIN1.32
D6: IC4.12 (D2), IC5.12 (D2), IC6.12 (D2), _PIN1.33
D7: IC4.11 (D3), IC5.11 (D3), IC6.11 (D3), _PIN1.34
GND: C1.2, C2.2, C3.2, C4.2, C5.2, C6.2, C7.2, IC1.9 (GND), IC2.9 (GND), IC3.9 (GND), IC4.9 (GND), IC5.9 (GND), IC6.9 (GND), IC7.8 (GND), _PIN1.17
unnamed: IC7.15 (Y0), JP1.1
unnamed: IC7.14 (Y1), JP1.3
unnamed: IC7.13 (Y2), JP1.5
unnamed: IC7.11 (Y4), JP2.1
unnamed: IC7.10 (Y5), JP2.3
unnamed: IC7.9 (Y6), JP2.5
VCC: C1.1, C2.1, C3.1, C4.1, C5.1, C6.1, C7.1, IC1.18 (VCC), IC2.18 (VCC), IC3.18 (VCC), IC4.18 (VCC), IC5.18 (VCC), IC6.18 (VCC), IC7.16 (VCC), _PIN1.18


Board: 2 copper layers, 101.3 x 38.1 mm, 17 parts (0 on the bottom side), 36 nets.

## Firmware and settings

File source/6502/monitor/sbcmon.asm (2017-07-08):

;---------------------------------------------------------------------
; Modified for RC2014
; Changes are copyright Ben Chong and freely licensed to the community
;
;---------------------------------------------------------------------
;  Original version information:
;       SBC Firmware V5.1.1, 7-4-13, by Daryl Rictor
;       5.1.1 Lite Version - removed List and Mini-Assembler & Help
;
;

CR		=	13
LF		=	10
ESC             =     27          ; ESC to exit

;input_char      = $ff03         ; wait for input character
;check_input     = $ff06         ; scan for input (no wait), C=1 char, C=0 no character
;output_char     = $ff09         ; send 1 character

;*********************************************************************       
;  local Zero-page variables
; Modified from Daryl's code so that we overlap with EhBASIC as little
; as possible. This was needed to debug EhBASIC during the porting process

ysav            =       $e0               ; 1 byte
Startaddr       =       $e1               ; 2 bytes
Startaddr_H     =       $e2
Hexdigits       =       $e3               ; 2 bytes
Hexdigits_H     =       $e4
strptr          =       $e5
strptrh         =       $e6		; temporary string pointer (not preserved across calls)

; Local Non-Zero Page Variables
; Unchange from Daryl's code except for addition of the interrupt vectors
buffer          =       $0300             ; keybd input buffer (127 chrs max)
uart_input_vecl =       $03d0           ;
uart_input_vech =       $03d1
uart_scan_vecl        =       $03d2
uart_scan_vech        =       $03d3
uart_output_vecl        =       $03d4
uart_output_vech        =       $03d5
PCH             =       $03e0             ; hold program counter (need PCH next to PCL for Printreg routine)
PCL             =       $03e1             ;  ""
ACC             =       $03e2             ; hold Accumulator (A)
XREG            =       $03e3             ; hold X register
YREG            =       $03e4             ; hold Y register
SPTR            =       $03e5             ; hold stack pointer
PREG            =       $03e6             ; hold status register (P)
irq_vector      =       $03e8           ; Interrupt vector
nmi_vector      =       $03ea           ; NMI vector
rowcount        =       $03eb               ; 1 byte
;dlfail    	=   	$03ec    	; flag for upload failure  
;old_irq_vectorl         =       $03f0           ; Where we save the old IRQ vector
;old_irq_vectorh         =       $03f1
;via6522_count           =       $03f2
;via6522_freqcntl        =       $03f3           ; Count to program into T1
;via6522_freqcnth        =       $03f4           ; Count to program into T1
;via6522_duration        =       $03f5           ; Duration in 10ms ticks
;

;
;               
; *************************************************************************
; kernal commands
; *************************************************************************
; PrintReg     - Prints CR, the register contents, CR, then returns
; Print2Byte   - prints AAXX hex digits
; Print1Byte   - prints AA hex digits
; PrintDig     - prints A hex nibble (low 4 bits)
; Print_CR     - prints a CR (ASCII 13)and LF (ASCII 10)
; PrintXSP     - prints # of spaces in X Reg
; Print2SP     - prints 2 spaces
; Print1SP     - prints 1 space
; Input_Char    - get one byte from input port, waits for input
; Output_char   - send one byte to the console
; *************************************************************************
;
;---------------------------------------------------------------------
; Print register contents
; Changed this for better clarity
RegData        .byte    " PC=  A=  X=  Y=  S=  P= "
FlagsData       .byte   CR,LF," NVRBDIZC",0
;
; Prints a CR, the register contents, CR, then returns
;
PrintReg       jsr   Print_CR          ; Lead with a CR
               ldx   #$ff              ;
               ldy   #$ff              ;
Printreg1      iny                     ;
               lda   Regdata,y         ;
               jsr   Output_char            ;
               cmp      #$3D            ; "="
               beq      printreg2
               cmp      #$00            ; End of FlagsData string?
               bne      Printreg1       ;
               inx
               jmp      printreg3
Printreg2      inx                     ;
               lda   PCH,x             ;  
               jsr   Print1Byte        ;
               cpx   #$00              ;
               bne   Printreg1         ;
               beq   Printreg2         ;
                ; Print flags detail
Printreg3       jsr     print_cr
                jsr     print1sp
                dex                     ;
               lda   PCH,x             ; get Preg
               ldx   #$08              ; 
Printreg4      rol                     ;
               tay                     ;
               lda   #$31              ;
               bcs   Printreg5         ;
               sbc   #$00              ; clc implied:subtract 1
Printreg5      jsr   Output_char            ;
               tya                     ;
               dex                     ;
               bne   Printreg4         ;
; fall into the print CR routine
;---------------------------------------------------------------------
; Print CR/LF
; Preserves A
Print_CR       PHA                     ; Save Acc
               LDA   #$0D              ; "cr"
               JSR   OUTPUT_char            ; send it
               LDA   #$0A              ; "lf"
               JSR   OUTPUT_char            ; send it
               PLA                     ; Restore Acc
               RTS                     ; 

;---------------------------------------------------------------------
; Prints AAXX hex digits
;
Print2Byte     JSR   Print1Byte        ;  prints AAXX hex digits
               TXA                     ;

;---------------------------------------------------------------------
; Prints AA hex digits
; A=byte
Print1Byte     PHA                     ;  Save A on stack
               LSR                     ;  MOVE UPPER NIBBLE TO LOWER
               LSR                     ;
               LSR                     ;
               LSR                     ;
               JSR   PrintDig          ; Print nibble
               PLA                     ;  Restore A

;---------------------------------------------------------------------
; Print lower nibble of A
;
PrintDig       sty   ysav              ;  prints A hex nibble (low 4 bits)
               AND   #$0F              ;
               TAY                     ;
               LDA   Hexdigdata,Y      ;
               ldy   ysav              ;
               jmp   output_char            ;
PrintXSP1      JSR   Print1SP          ;
               dex                     ;
PrintXSP       cpx   #$00              ;
               bne   PrintXSP1         ;
               rts                     ;
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

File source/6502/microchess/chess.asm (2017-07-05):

; Modified for MON6502 for the RC2014
; Uses the BIOS for console I/O
; Added support for ANSI/VT100 terminals that support various advanced features
;
;***********************************************************************
;
;  Kim-1 MicroChess (c) 1976-2005 Peter Jennings, www.benlo.com 
;
;***********************************************************************

; All rights reserved.

; Redistribution and use in source and binary forms, with or without
; modification, are permitted provided that the following conditions
; are met:
; 1. Redistributions of source code must retain the above copyright
;    notice, this list of conditions and the following disclaimer.
; 2. Redistributions in binary form must reproduce the above copyright
;    notice, this list of conditions and the following disclaimer in the
;    documentation and/or other materials provided with the distribution.
; 3. The name of the author may not be used to endorse or promote products
;    derived from this software without specific prior written permission.

; THIS SOFTWARE IS PROVIDED BY THE AUTHOR ''AS IS'' AND ANY EXPRESS OR
; IMPLIED WARRANTIES, INCLUDING, BUT NOT LIMITED TO, THE IMPLIED WARRANTIES
; OF MERCHANTABILITY AND FITNESS FOR A PARTICULAR PURPOSE ARE DISCLAIMED.
; IN NO EVENT SHALL THE AUTHOR BE LIABLE FOR ANY DIRECT, INDIRECT,
; INCIDENTAL, SPECIAL, EXEMPLARY, OR CONSEQUENTIAL DAMAGES (INCLUDING, BUT
; NOT LIMITED TO, PROCUREMENT OF SUBSTITUTE GOODS OR SERVICES; LOSS OF USE,
; DATA, OR PROFITS; OR BUSINESS INTERRUPTION) HOWEVER CAUSED AND ON ANY
; THEORY OF LIABILITY, WHETHER IN CONTRACT, STRICT LIABILITY, OR TORT
; (INCLUDING NEGLIGENCE OR OTHERWISE) ARISING IN ANY WAY OUT OF THE USE OF
; THIS SOFTWARE, EVEN IF ADVISED OF THE POSSIBILITY OF SUCH DAMAGE.

;
; modified by Daryl Rictor to work over a 
; serial terminal connection, August 2002.
;
; Updated with corrections to earlier OCR errors by Bill Forster, August 2005.
;
;   cpu 65c02
;   page 0,132
;
;
; Vector addresses for console I/O
input_char      = $ff03
check_input     = $ff06
output_char     = $ff09

;
; page zero variables
;
BOARD   =	$50 
BK      =	$60 
PIECE   =	$B0 
SQUARE  =	$B1 
SP2     =	$B2 
SP1     =	$B3 
INCHEK  =	$B4 
STATE   =	$B5 
MOVEN   =	$B6 
REV	=       $B7
OMOVE   =	$DC 
WCAP0   =	$DD 
COUNT   =	$DE 
BCAP2   =	$DE 
WCAP2   =	$DF 
BCAP1   =	$E0 
WCAP1   =	$E1 
BCAP0   =	$E2 
MOB     =	$E3 
MAXC    =	$E4 
CC      =	$E5 
PCAP    =	$E6 
BMOB    =	$E3 
BMAXC   =	$E4 
BMCC    =	$E5 		; was BCC (TASS doesn't like it as a label)
BMAXP   =	$E6 
XMAXC   =	$E8 
WMOB    =	$EB 
WMAXC   =	$EC 
WCC     =	$ED 
WMAXP   =	$EE 
PMOB    =	$EF 
PMAXC   =	$F0 
PCC     =	$F1 
PCP     =	$F2 
OLDKY   =	$F3 
BESTP   =	$FB 
BESTV   =	$FA 
BESTM   =	$F9 
DIS1    =	$FB 
DIS2    =	$FA 
DIS3    =	$F9 
temp    =       $FC
ysav    =       $fd
;
;
;
;		*=$1000			; load into RAM @ $1000-$15FF
        .org $1000

        jsr     clear_screen
	LDA     #$00		; REVERSE TOGGLE
	STA     REV
;                JSR     Init_6551
CHESS
;		CLD			; INITIALIZE
		LDX	#$FF		; TWO STACKS
		TXS	
		LDX	#$C8
		STX	SP2
;		
;       ROUTINES TO LIGHT LED
;       DISPLAY AND GET KEY
;       FROM KEYBOARD
;		
OUT
		JSR	pout		; DISPLAY AND
bad_key
                lda     #$0d
                jsr     output_char
		JSR	KIN		; GET INPUT   *** my routine waits for a keypress
;		CMP	OLDKY		; KEY IN ACC  *** no need to debounce
;		BEQ	OUT		; (DEBOUNCE)
;		STA	OLDKY
;
                cmp     #$0d             ; ENTER
                beq     nogo
                cmp     #'0'
                bcc     bad_key         ; < 0 -> bad key
                ; >= 0
                cmp     #$3A    ;':'
                bcs     not_number
                and     #$4f
                jmp     input
not_number:
                and     #$5f
		CMP	#$43		; [C]
		BNE	NOSET		; SET UP
		LDX	#$1F		; BOARD
WHSET		LDA	SETW,X		; FROM
		STA	BOARD,X		; SETW
		DEX	
		BPL	WHSET
		LDX	#$1B		; *ADDED
		STX	OMOVE		; INITS TO $FF
		LDA	#$CC		; Display CCC
		BNE	CLDSP
;		
NOSET		CMP	#$45		; [E]
		BNE	NOREV		; REVERSE
		JSR	REVERSE        	; BOARD IS
		SEC
		LDA	#$01
		SBC	REV
		STA	REV		; TOGGLE REV FLAG
		LDA	#$EE            ; IS
		BNE	CLDSP
;		
NOREV		CMP	#$50		; [P]
		BNE	NOGO           	; PLAY CHESS
		JSR	GO
CLDSP		STA	DIS1          	; DISPLAY
		STA	DIS2         	; ACROSS
		STA	DIS3          	; DISPLAY
		BNE	CHESS
;		
NOGO		CMP	#$0D            ; [Enter]
		BNE	NOMV          	; MOVE MAN
		JSR	MOVE          	; AS ENTERED
		JMP	DISP
NOMV
                jsr     output_char
		CMP     #$51		; [Q] ***Added to allow game exit***
		BEQ     DONE		; quit the game, exit back to system.  
;		JMP	INPUT		; process move
        jmp     bad_key
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

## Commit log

2017-04-09 Eagle files for RC2014 add-on boards
    [rc2014_template.brd, rc2014_template.sch]
2017-04-10 Fix wiring issue with template
    [rc2014_template.brd, rc2014_template.sch]
2017-04-16 Added 16550 board and new CPU board
    [rc2014_16550.brd, rc2014_16550.sch, rc2014_z80plus.brd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]
2017-04-18 8085 CPU Board
    [rc2014_8085.brd, rc2014_8085.sch]
2017-04-22 Real Retro 3KB RAM board
    [rc2014_3kb_ram.brd, rc2014_3kb_ram.sch]
2017-04-22 screenshot of board
2017-04-23 Add pdf of schematic
2017-04-25 Add support for 16550/16C550 UART with the 16x550 UART card
2017-04-25 Add link to OSH Park to order the 16x550 UART card
2017-04-26 Add signal labels and PDF of schematic
    [rc2014_8085.sch]
2017-04-26 NSC800 CPU board
    [rc2014_nsc800.brd, rc2014_nsc800.sch]
2017-04-26 Add png of board
2017-04-29 Clean up stencils
    [rc2014_z80plus.brd]
2017-04-29 Update resistor values
    [rc2014_z80plus.sch]
2017-04-29 Fixed wiring error on PCB
    [rc2014_8085.brd]
2017-04-30 Clean up, add CLK
    [rc2014_8085.brd, rc2014_8085.sch]
2017-05-09 Fix missing A1, A0 lines
    [rc2014_3kb_ram.brd, rc2014_3kb_ram.sch]
2017-05-11 Add 16550 UART Board Rev B
    [rc2014_16550b.brd, rc2014_16550b.sch]
2017-05-11 Update README.md for the Real Retro 3KB RAM board
2017-05-12 Update BIOS to support the 16550 Rev B board
2017-05-12 Correctly identify 74LS03
    [rc2014_16550b.sch]
2017-05-12 Update 8085 board includeing OSH Park link
2017-05-12 Correct 20pF capacitor value for <4MHz crystal
    [rc2014_8085.sch]
2017-05-14 Real Retro UART Board
    [rc2014_rruart.brd, rc2014_rruart.sch]
2017-05-17 Add BIOS and Monitor ROM for Real Retro UART Board
2017-05-20 Simple ROM RAM board for the RC2014
    [rc2014_romram.brd, rc2014_romram.sch]
2017-05-28 6502 CPU Board
    [rc2014_6502.brd, rc2014_6502.sch]
2017-05-29 BIOS for 16C550 UART
2017-05-29 Fix bug with ? command
    [sbcmon.asm]
2017-06-01 Squeeze Monitor into top 1K, use common function names for UART for compatibility
2017-06-02 Fix instability with upload
    [upload.asm]
2017-06-02 Update README.md
    JP1 should be shorted to GND when NOT using the WDC chip. On the WDC chip, VPB (Vector Pull (Bar)) is an output that should be disconnected.
2017-06-03 Version 0.1.2 with bug fixes and better alignment with Z80 monitor debugger user interface
    [sbcmon.asm]
2017-06-04 More bug fixes and optimizations. Added U as an explicit upload command
    [16c550.asm, sbcmon.asm, upload.asm]
2017-06-04 Consolidate error handling for upload.asm
    [sbcmon.asm, upload.asm]
2017-06-06 Add support for the RC2014 Serial IO board
2017-06-18 Bring in ROM images for other UARTs
2017-06-20 6502 CPU Board RevB
    [rc2014_6502.brd, rc2014_6502.sch]
2017-06-24 16550 UART Board RevC
    [rc2014_16550c.brd, rc2014_16550c.sch]
2017-07-02 Initial check-in for 6522 sample code
2017-07-03 6522 VIA Board for RC2014
    [rc2014_6522.brd, rc2014_6522.sch]
2017-07-03 Test interleaving interrupts
2017-07-05 Correct timer value for 10ms tick
2017-07-08 Add support for 16C750 UART with 64char FIFO
2018-05-06 6809 CPU board
    [rc2014_6809.brd, rc2014_6809.sch]
2018-05-12 Fixed typos, add speaker driver schematic and update README with more instructions
2018-05-12 PDF versions of the schematic and board layout
2018-05-12 Picture of the 6522 board with driver and mini-speaker
